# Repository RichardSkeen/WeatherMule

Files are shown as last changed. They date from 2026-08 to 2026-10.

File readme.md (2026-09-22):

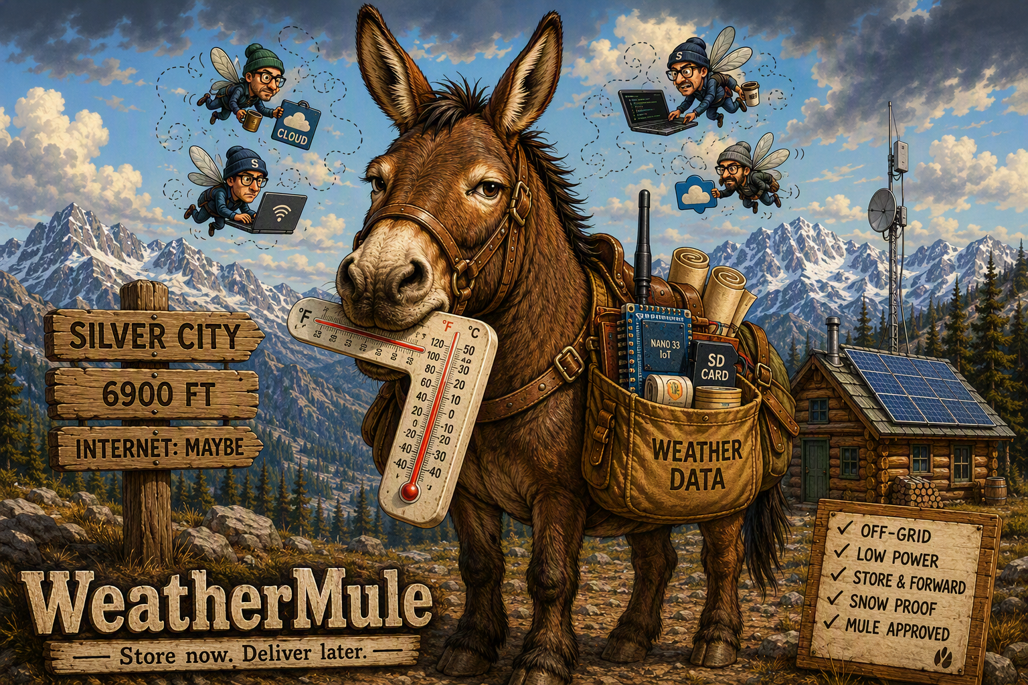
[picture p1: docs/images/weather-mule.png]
Weather Mule


*Not interested in deep dive?*
```cpp
if (!Interested)
{
    Read("docs/readme.md").JumpTo(start => "Technical Documentation" || "docs/technical/");
}
else
{
    enjoy = true;
}
```

# WeatherMule

> **Store now. Deliver later.**

WeatherMule is a store-and-forward weather relay built for remote weather stations where internet connectivity is less reliable than the weather itself.

Designed for an off-grid cabin in Silver City, California. WeatherMule captures weather observations, stores them locally on an SD card, and delivers them to PackStationWeather when network connectivity becomes available.

Because storms don't wait for Wi-Fi.

## Features

- 🐴 Store-and-forward weather delivery
- 💾 Local SD-card archive
- 🌲 Designed for remote and off-grid deployments
- 🔋 Low-power Arduino Nano 33 IoT platform
- 🌨️ Built for harsh mountain weather
- 📦 Automatic recovery of missing observations
- 🚫 No cloud dependency required

## Why?

Most weather systems assume the network is always available.

WeatherMule assumes the weather is always available.

The difference matters when the interesting weather arrives at the same time the internet disappears.

## Documentation

- docs/project-story.md
- docs/design.md
- docs/silver-city-use-case.md
- docs/deployment.md

## The Guiding Principle

> Save the weather first.  
> Figure everything else out later.

---

**WeatherMule:** Off-grid. Low-power. Store-and-forward. Snow-aware. Mule-approved.

### [Documentation Index](docs/readme.md)

---

## Related Project

### PackStationWeather

The destination at the end of the trail.

📖 [Building Our Own Pack Station](docs/project-story/pack-station-weather.md)

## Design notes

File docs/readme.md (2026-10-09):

# WeatherMule Documentation

This documentation is organized into technical references, project stories, hardware references, and supporting materials.

For readers new to the project, follow the documents below in order. Each document builds on the previous one and gradually moves from understanding what WeatherMule does to understanding how it is implemented.

## [Technical Documentation](technical/)

1. [quick-start.md](technical/quick-start.md)  
   Begin here. Provides a high-level introduction to WeatherMule and the quickest path to understanding the project.

2. [architecture.md](technical/architecture.md)  
   Describes the major components of WeatherMule and the responsibilities assigned to each subsystem.

3. [flow-storage.md](technical/flow-storage.md)  
   Describes the flow of data through the WeatherMule storage subsystem, from request to response.

4. [flow-application.md](technical/flow-application.md)  
   Describes the flow of data through the WeatherMule application, from weather station to storage and delivery.

5. [flow-weather-request.md](technical/flow-weather-request.md)  
   Describes the flow of a weather station request through the WeatherMule application, from request to response.

6. [flow-authentication.md](technical/flow-authentication.md)  
   Describes the flow of an authentication request through the WeatherMule application, from request to response.

7. [flow-upload-observation.md](technical/flow-upload-observation.md)  
   Describes the flow of an observation upload through the WeatherMule application, from request to response.

8. [flow-hole-processing.md](technical/flow-hole-processing.md)  
   Describes the flow of a hole processing request through the WeatherMule application, from request to response.

9. [source-map.md](technical/source-map.md)  
   Maps source files to responsibilities. Use this document when locating where specific functionality is implemented.

## [Project Story](project-story/)

The project stories describe how WeatherMule evolved, why design decisions were made, and lessons learned during development.

1. [silver-city-use-case.md](project-story/silver-city-use-case.md)  
   Describes the initial use case that motivated the WeatherMule project.

2. [life-of-a-weather-observation.md](project-story/life-of-a-weather-observation.md)  
   Explains how a weather observation moves through the system, from creation to storage and delivery.

3. [weather-station-data.md](project-story/weather-station-data.md)  
   Explains how the Ambient Weather protocol was discovered and validated.  

4. [pack-station-weather.md](project-story/pack-station-weather.md)  
   Describes how the PackStation weather station was integrated into WeatherMule.

5. [packbox-storage.md](project-story/packbox-storage.md)  
   Describes the design and implementation of the PackBox storage system.

6. [authentication.md](project-story/authentication.md)  
   Explains how authentication was implemented in WeatherMule.

7. [unload-weather.md](project-story/unload-weather.md)  
   Explains how the mule unloads weather observations to the pack station.

8. [holes.md](project-story/holes.md)  
   Explains how holes in the weather observation data are detected and processed.
## Future Development
#### V2
1.[v2-weather-station-manifest-design.md](future/v2/v2-weather-station-manifest-design.md)  
  Weather station manifest and configuration management.

## Hardware

Hardware-specific documentation is located in the hardware/ folder.

1. [ambient-weather-2000.md](hardware/ambient-weather-2000.md)  
2. [arduino.md](hardware/arduino.md)
3. [enclosure.md](hardware/enclosure.md)

## Reference Material

Reference documents contain vendor-specific information and supporting research used throughout the project.

1. [ambient-device-data-specs.md](reference/ambient-device-data-specs.md)  
   Reference documentation from Ambient Weather describing the weather station observation fields.

2. [protocol-discovery.md](reference/protocol-discovery.md)  
   Documents how the Ambient Weather protocol was analyzed, validated, and incorporated into WeatherMule.

---

## Related Project

### PackStationWeather

The destination at the end of the trail.

📖 [Building Our Own Pack Station](project-story/pack-station-weather.md)

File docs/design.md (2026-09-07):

# WeatherMule Design

## Overview

WeatherMule is a store-and-forward weather relay designed for locations where weather observations are more reliable than internet connectivity.

The primary objective is simple:

```text
Never lose weather observations.
```

WeatherMule receives weather data from an Ambient Weather WS2000, stores observations locally on SD card, maintains current weather statistics, and attempts to synchronize missing observations when connectivity allows.

---

# High-Level Architecture

```text
                 +----------------+
                 | Ambient Weather|
                 +--------+-------+
                          ^
                          |
                          |
                 +--------+-------+
                 |  WeatherMule   |
                 | Arduino Nano   |
                 +--------+-------+
                          ^
                          |
                          |
                 +--------+-------+
                 |     WS2000     |
                 +----------------+
```

The weather station transmits observations to both Ambient Weather and WeatherMule.

WeatherMule acts as a passive observer and backup delivery service.

---

# Core Design Principles

## Preserve Data First

Weather observations are more valuable than network status.

When in doubt:

```text
Save the observation.
```

Synchronization can happen later.

Lost observations cannot be recovered.

---

## Store Facts

WeatherMule stores the original weather observation exactly as received.

Example:

```text
GET /data/report/&PASSKEY=...
```

Derived values can always be recalculated later.

Original observations cannot.

---

## Simplicity Over Cleverness

WeatherMule is intended to operate:

- unattended
- off-grid
- on limited power
- in remote locations

Simple systems are easier to recover and maintain.

---

# Storage Model

WeatherMule uses two storage types.

## Packboxes (.box)

Packboxes contain the permanent weather archive.

Example:

```text
20260815.box
20260816.box
20260817.box
```

Each packbox contains observations received during a single day.

Example contents:

```text
GET /data/report/&PASSKEY=...
GET /data/report/&PASSKEY=...
GET /data/report/&PASSKEY=...
```

Packboxes are append-only.

Packboxes are the source of truth.

---

## Wrangler's Notebook (current.json)

current.json stores operational state.

Example:

```json
{
  "CurrentPackbox": "20260815.box",

  "LatestLocalUtc": "2026-08-15T22:18:21Z",
  "LatestAmbientUtc": "2026-08-15T17:58:21Z",

  "DailyLowTempF": 58.7,
  "DailyHighTempF": 90.9,

  "MaxWindGust": 15.88
}
```

This file contains:

- synchronization status
- current statistics
- upload progress
- current packbox information

Unlike packboxes, current.json may be overwritten frequently.

---

# WeatherRequest

WeatherMule receives weather observations using HTTP requests.

The WeatherRequest class:

```cpp
WeatherRequest
```

provides:

```text
Raw Request
+
Parsed Parameters
```

Example:

```text
GET /data/report/&PASSKEY=...
```

becomes:

```text
PASSKEY
dateutc
tempf
humidity
windspeedmph
...
```

The raw request is used for storage and replay.

The parsed values are used for statistics and reporting.

---

# Statistics

WeatherMule maintains a running summary of weather conditions.

Examples:

```text
Daily Low Temperature
Daily High Temperature

Maximum Wind Gust

Latest Observation

Rainfall Totals
```

Statistics are updated as observations are received.

Historical packboxes never need to be rescanned during normal operation.

---

# Synchronization Strategy

Traditional systems check:

```text
Is the network available?
```

WeatherMule attempts to answer:

```text
Is Ambient Weather missing observations?
```

Example:

```text
Ambient Latest:
17:58 UTC

WeatherMule Latest:
22:18 UTC
```

Result:

```text
Ambient is behind.
```

WeatherMule should determine which observations are missing and attempt synchronization.

The reason for the outage is irrelevant.

Possible causes include:

- Internet outage
- Ambient outage
- Router outage
- DNS failure
- Power interruption

WeatherMule cares only about whether the cargo was delivered.

---

# Timestamp Authority

WS2000 observations include:

```text
dateutc=YYYY-MM-DD HH:MM:SS
```

WeatherMule treats the weather station timestamp as authoritative for the observation.

This avoids dependence on local clocks and external time services.

---

# Future Work

Planned areas of investigation:

## Ambient Synchronization

Determine:

- Ambient upload destination
- Ambient response behavior
- Historical upload support
- Duplicate handling behavior

## Packbox Recovery

Determine optimal strategy for:

- locating missing observations
- replaying missed observations
- recovering after power loss

## Statistics

Expand locally maintained statistics while preserving simplicity.

---

# Design Vocabulary

WeatherMule uses a pack-train metaphor throughout the project.

| Term | Meaning |
|---|---|
| Cargo | Weather observations |
| Packbox | Daily `.box` file |
| Cargo Manifest | WeatherRequest |
| Wrangler's Notebook | current.json |
| Mule Train | Collection of packboxes |
| Delivery | Synchronization with Ambient |

Cute = Bad

Meaningful = Good

Cute + Meaningful = Priceless.

---

# Guiding Principle

The mule does not care why the cargo was not delivered.

The mule only cares whether the cargo was delivered.

## Possible WeatherMule Enclosure

The WeatherMule enclosure may be based on a modified 3D model of a pack mule. The mule body would be hollowed to contain the Nano 33 IoT, SD storage, wiring, and future expansion components. The saddle or tack assembly could serve as a removable service panel.

Potential source model:
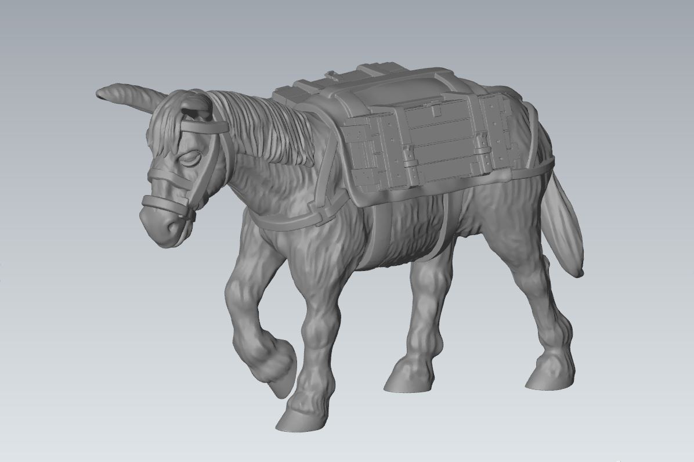
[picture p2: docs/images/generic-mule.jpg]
Mule 3D Model

[WeatherMule enclosure](https://www.myminifactory.com/object/3d-print-28-mm-generic-mule-tow-550193)

Ideas:
- Hollow body cavity for electronics.
- Saddle removable for maintenance access.
- OLED "Pack Tag" display mounted on a packbox.
- RGB status LED visible from outside the enclosure.
- USB access hidden beneath packbox or saddle.
- Device physically embodies the WeatherMule concept by carrying observations in digital packboxes to the PackStation.

Status: Future investigation. Verify model scale and available internal volume before purchase.

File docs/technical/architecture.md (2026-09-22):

# Purpose

WeatherMule is an embedded store-and-forward relay for weather observations.

Its responsibility is to:

- Receive weather observations from an Ambient Weather station.
- Preserve observations locally on removable storage.
- Forward observations to PackStationWeather.
- Recover from communication outages.
- Synchronize observations that were missed by the server.
- Operate unattended in environments where network connectivity may be unreliable.

WeatherMule treats the original weather observation as the source record and stores observations before attempting remote delivery. Local storage allows observations to be replayed later if PackStationWeather is unavailable.

The system is designed around reliability, recoverability, and low operational complexity rather than real-time delivery guarantees.

# Core Principles

## Preserve Data Before Delivery

Weather observations are stored locally before remote delivery is attempted. Local storage ensures observations remain available even when PackStationWeather, network connectivity, or supporting infrastructure are unavailable.

## Store Original Observations

WeatherMule preserves the original weather station observation as received. The original observation is considered the source record. Derived values and statistics may be recalculated later from the stored observations.

## Stored Original Observations Are the Source of Truth

Packboxes (.box files) serve as the authoritative record of observations retained by WeatherMule. Operational state and synchronization status may be recreated from packbox data if necessary.

## Recovery Is a Normal Operation

Network interruptions, power failures, and service outages are expected operating conditions. The system is designed to identify missing observations and recover delivery through synchronization processes.

## Prefer Simple and Observable Behavior

The system favors straightforward implementations that are easy to understand, troubleshoot, and recover in remote deployments. Simplicity is preferred over optimization unless a measurable benefit exists.

## Operate Unattended

WeatherMule is intended to operate for extended periods without human intervention. Normal processing, storage, delivery, and recovery operations should occur automatically whenever possible.

# System Components

## WeatherMule

WeatherMule is the application entry point.

Responsibilities:

- Connect to WiFi.
- Initialize local storage.
- Accept weather station requests.
- Coordinate upload and synchronization activities.
- Process holes when observations are not being received.

Primary file:

- WeatherMule.ino

## WeatherRequest

WeatherRequest parses incoming weather station requests and exposes observation values as key/value pairs.

Responsibilities:

- Parse incoming HTTP requests.
- Extract weather observation parameters.
- Provide access to individual values.
- Serialize observations for API transport.

Primary file:

- WeatherRequest.h

## Weather Station Interface

The Weather Station Interface receives observations from the weather station and coordinates local storage and delivery.

Responsibilities:

- Receive weather station requests.
- Validate observation requests.
- Store observations locally.
- Upload observations to PackStationWeather.
- Return HTTP responses to the weather station.

Primary file:

- WeatherStationRoutines.h

## Storage Subsystem

The Storage Subsystem manages persistent local storage using packboxes.

Responsibilities:

- Create daily packboxes.
- Append observations.
- Locate observations for synchronization.
- Read observations from historical packboxes.
- Maintain recovery data required for hole filling.

Primary file:

- StorageRoutines.h

## API Client

The API Client manages communication with PackStationWeather.

Responsibilities:

- Authenticate with PackStationWeather.
- Maintain session and refresh tokens.
- Upload observations.
- Report observations that cannot be recovered.
- Retrieve hole information.

Primary file:

- ApiClientRoutines.h

## Hole Processor

The Hole Processor recovers observations that are missing from PackStationWeather.

Responsibilities:

- Track holes returned by the server.
- Locate missing observations in packboxes.
- Upload recovered observations.
- Report observations that can no longer be located.
- Remove completed holes from processing.

Primary file:

- HoleRoutines.h

## API Response Parser

The API Response Parser provides lightweight JSON parsing for responses returned by PackStationWeather.

Responsibilities:

- Parse API responses.
- Extract property values.
- Convert JSON arrays and objects into navigable structures.

Primary file:

- ApiResponse.h

# Packboxes

Packboxes are the persistent storage mechanism used by WeatherMule.

A packbox is a daily append-only file containing the original weather station observations received during a single UTC date. Packboxes provide the durable record used for recovery, synchronization, and future processing.

## Naming

Packboxes are named using the observation date.

Examples:

2026-08-15.box
2026-08-16.box
2026-08-17.box

The date portion is derived from the observation timestamp rather than the device clock.

## Contents

Each line within a packbox contains a complete weather station observation in its original form.

Example:

GET /data/report/&PASSKEY=...

Observations are stored without modification to preserve the original source record.

## Append-Only Design

New observations are always appended to the end of the appropriate packbox.

Existing observations are never modified or removed.

This design:

- minimizes write operations
- simplifies recovery
- reduces the risk of corruption
- preserves original observations

## Source of Truth

Stored observations within packboxes are considered the authoritative record maintained by WeatherMule.

Synchronization, hole filling, and future processing operations are performed using observations recovered from packboxes.

Derived statistics and operational state may be recreated from packbox contents if necessary.

## Synchronization

When PackStationWeather identifies missing observations, WeatherMule locates the corresponding records within the appropriate packbox and replays them to the server.

Packboxes therefore serve as both:

- the local archive
- the recovery mechanism

## Recovery

Packboxes allow WeatherMule to recover from interruptions including:

- network outages
- server outages
- power interruptions
- device restarts

As long as observations have been successfully written to a packbox, they remain available for future delivery attempts.

# Authentication

WeatherMule authenticates with PackStationWeather using a two-stage token process.

## API Key

Each WeatherMule instance is configured with a unique API key.

The API key is a long-lived credential and is typically used only when establishing a new authenticated session.

## Check-In

WeatherMule performs a check-in operation when:

- no Session Token is available
- a Session Token has expired
- a Session Token has been revoked
- no Refresh Token is available
- a Refresh Token has expired
- a Refresh Token has been revoked

A successful check-in returns:

- Session Token
- Refresh Token

These tokens are stored in memory and used for subsequent communication.

## Token Lifecycle

The Session Token is intended for normal API operations and has a relatively short lifetime.

The Refresh Token has a longer lifetime and is used to obtain a replacement Session Token when the current Session Token expires.

During normal operation:

1. WeatherMule authenticates using the API Key.
2. PackStationWeather returns a Session Token and Refresh Token.
3. API requests use the Session Token.
4. When the Session Token expires, WeatherMule performs another check-in using the Refresh Token.
5. PackStationWeather returns a replacement Session Token.
6. Normal operation continues.

The API Key is normally not transmitted again until both token-based mechanisms become unavailable.

## Refresh Token Rotation

Refresh Tokens may be rotated during Session Token renewal.

When a new Refresh Token is issued, it inherits the remaining expiration period of the token it replaces rather than creating a new refresh window.

This approach:

- limits long-term exposure of a Refresh Token
- reduces repeated transmission of the API Key
- preserves the original refresh-token expiration policy
- allows token values to change periodically during normal operation

## Authentication Failure

If token-based authentication fails, WeatherMule falls back to API Key authentication by performing a new check-in.

Authentication failures do not affect local observation storage. Observations continue to be preserved within packboxes and may be replayed after authentication is restored.

# Holes

A hole represents a range of observations that PackStationWeather expects to exist but cannot locate within its observation history.

Holes are identified by PackStationWeather and returned to WeatherMule during normal upload operations.

## Hole Structure

A hole contains:

- Vendor Device Key
- From UTC
- To UTC
- Partially Filled (used only by WeatherMule to track progress)
- Byte Offset (used only by WeatherMule to track progress)

The time range defines the missing observations between FromUtc and ToUtc.

Example:

{
    "vendorDeviceKey": "...",
    "fromUtc": "2026-08-15T17:00:00Z",
    "toUtc": "2026-08-15T18:00:00Z",
    "partiallyFilled": false,
    "byteOffset": 0
}

Primary file:

Hole.h

## Hole Processing

When a hole is received, WeatherMule locates observations associated with the hole and gradually replays missing observations to PackStationWeather.

Hole recovery is performed incrementally rather than as a single batch operation. This allows WeatherMule to remain responsive to new observations while recovery is in progress.

Progress is tracked so recovery can resume efficiently between processing cycles.

Hole processing continues until the boundary identified by ToUtc is reached or until WeatherMule determines that additional observations are unavailable.

Holes are transient recovery instructions rather than permanent state.

Whenever a new observation is successfully uploaded, any unfinished holes are discarded. PackStationWeather returns a new set of holes if any still exist.

This allows PackStationWeather to remain the authority for determining which observations are still missing while keeping WeatherMule focused on recovering only currently relevant gaps.

# Recovery

WeatherMule is designed to recover from temporary interruptions without losing previously stored observations.

Recovery is based on the assumption that communication failures are normal operating conditions rather than exceptional events.

## Recovery Sources

Recovery is performed using observations stored in packboxes.

As long as an observation has been successfully written to a packbox, WeatherMule retains the information required to attempt future delivery.

## Recoverable Conditions

WeatherMule can recover from conditions including:

- network interruptions
- PackStationWeather outages
- authentication failures
- device restarts
- temporary power interruptions

Recovery occurs automatically during normal operation.

## Recovery Process

After communication with PackStationWeather is restored, WeatherMule uploads new observations as they are received.

PackStationWeather identifies any gaps in its observation history and returns the corresponding holes.

WeatherMule uses the holes to locate and replay missing observations from packboxes until the identified gaps have been resolved or until additional observations cannot be located.

## Recovery Authority

PackStationWeather is responsible for determining which observations are missing.

WeatherMule is responsible for locating and replaying observations requested by PackStationWeather.

This separation allows recovery decisions to be made using the server's complete observation history while allowing WeatherMule to focus on preservation and delivery of observations.

## Recovery Limitations

Recovery requires that observations have been successfully stored in a packbox.

Observations that were never received or could not be stored cannot be recovered.

When PackStationWeather requests observations that WeatherMule cannot locate, the condition is reported as Not Observed.

# Design Vocabulary

WeatherMule uses a pack-train metaphor to provide consistent terminology throughout the project.

| Term | Meaning |
|---|---|
| WeatherMule | The Arduino-based store-and-forward weather relay |
| Cargo | Weather observations |
| Packbox | A daily `.box` file containing stored observations |
| Mule Train | The complete collection of packboxes |
| [PackStationWeather](../pack-station-weather.md) | The server responsible for observation storage, authentication, and hole identification |
| Hole | A range of observations expected by PackStationWeather but not currently available in its observation history |
| Check-In | Authentication request used to obtain Session and Refresh tokens |
| Delivery | Successful upload of an observation to PackStationWeather |
| Replay | Resending a previously stored observation from a packbox |
| Not Observed | A condition indicating WeatherMule cannot locate an observation requested by a hole |

The design vocabulary exists to provide concise terminology for concepts that appear frequently throughout the codebase, documentation, and operational workflows.

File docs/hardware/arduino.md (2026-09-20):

# Arduino Nano Hardware

The PackStationWeather field stations use an Arduino Nano as the primary data acquisition controller. The Nano is responsible for collecting sensor measurements, managing local device interfaces, buffering readings as needed, and communicating with the WeatherMule data transport subsystem.

## Why the Nano?

The Arduino Nano provides several advantages for remote weather station deployments:

- Low power consumption
- Proven reliability in field environments
- Compact form factor
- Extensive sensor library support
- Simple USB programming and debugging
- Large community support and documentation

These characteristics make the Nano a practical choice for unattended deployments where stability and recoverability are more important than raw processing power.

## Architecture

The Nano serves as the weather station's edge controller.

Responsibilities include:

- Reading weather sensors
- Collecting environmental measurements
- Managing station health information
- Maintaining local operational state
- Providing data to WeatherMule for transport to PackStationWeather

```mermaid
flowchart TD
    A[Weather Sensors]
    B[Arduino Nano]
    C[Connection Carrier]
    D[WeatherMule Firmware]
    E[PackBox Storage]
    F[PackStationWeather API]

    A --> B
    B --> C
    C --> D

    D --> E
    D --> F
```

## Connection Carrier

The Arduino Nano is mounted on a Connection Carrier board.

There is no technical requirement to use this specific carrier. The primary reason it was selected is because there was one sitting in the parts drawer when the project started.

That said, it turned out to be a convenient choice because it provides screw-terminal connections, simplifies wiring, and makes field maintenance easier than loose jumper wires.

WeatherMule does not depend on any proprietary carrier-board functionality. The carrier simply provides convenient access to the Nano's I/O pins.

## Documentation

### Arduino Nano

Official hardware documentation:

https://docs.arduino.cc/hardware/nano-33-iot/

### Connection Carrier

Connection Carrier documentation:

https://docs.arduino.cc/hardware/nano-connector-carrier/

## Operating Environment

The Nano is designed to operate continuously in remote field locations. Weather station enclosures should provide protection from:

- Moisture
- Condensation
- Direct precipitation
- Dust
- Insects
- Excessive heat exposure

All external wiring should include proper strain relief and weather-resistant connectors appropriate for the deployment environment.

## Deployment Notes

The Nano firmware is developed specifically for the PackStationWeather ecosystem and may differ from reference Arduino examples.

When deploying or updating a station:

1. Verify firmware version.
2. Verify sensor connectivity.
3. Verify WeatherMule communication.
4. Verify accurate timestamps.
5. Confirm successful data delivery to PackStationWeather.

A successful deployment allows the station to collect weather observations locally while WeatherMule handles transport, synchronization, and recovery of missing observations.

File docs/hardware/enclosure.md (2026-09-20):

# WeatherMule Enclosure Concept

This document describes a proposed enclosure concept for WeatherMule.

The enclosure has not yet been printed, assembled, or field tested. At the time of writing, it exists only as a digital model and a growing list of ideas.

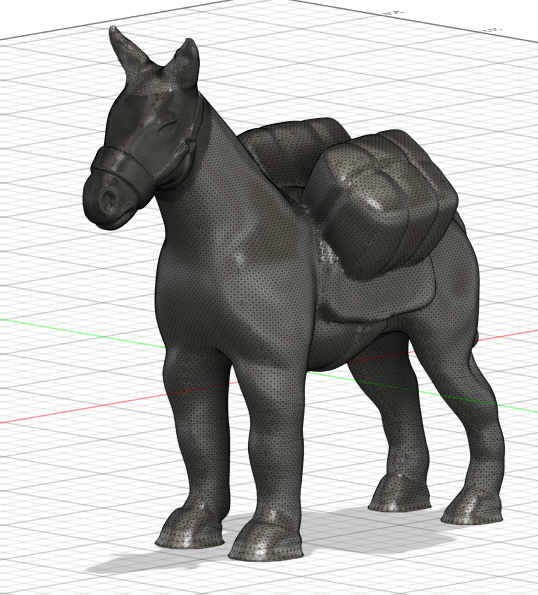
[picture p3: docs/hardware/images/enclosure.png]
Weatheer Mule Model


## Background

Most electronics projects eventually end up inside a generic plastic box.

While there is nothing wrong with that approach, the WeatherMule project presents a unique opportunity.

If the firmware responsible for collecting, storing, and delivering weather observations is called *WeatherMule*, perhaps the enclosure should look the part.

The current concept explores using a 3D printed pack mule as the enclosure for the Arduino Nano and Connection Carrier.

## Design Goals

The enclosure should:

- Protect the Arduino Nano and Connection Carrier
- Provide access to power and sensor connections
- Allow maintenance and firmware updates
- Be printable on a consumer-grade 3D printer
- Be easy to assemble and service
- Add a little personality to the project

The intent is not to create a sculpture. The intent is to create a practical enclosure that also happens to look like the project it contains.

## Why a Mule?

WeatherMule acts as a transporter of observations.

When a weather station reports data, the mule receives it, stores it when necessary, and delivers it to PackStationWeather when connectivity is available.

It is only fitting that the Arduino Nano should reside within the belly of a pack mule. After all, if the firmware is called WeatherMule, the hardware ought to look capable of carrying a few PackBoxes up a mountain trail.

## Proposed Layout

The current concept places the Arduino Nano and Connection Carrier within the body of the mule.

The saddlebags provide an interesting opportunity for future expansion and visual feedback.

Possible uses include:

- E-ink status displays
- Project branding
- Station identification
- Weather summaries
- Battery or power information
- Connectivity status

The final arrangement has not yet been determined and will likely evolve as prototypes are tested.

## Electronics

The current WeatherMule hardware is intentionally simple.

The design presently consists of:

- Arduino Nano
- Connection Carrier

WiFi connectivity is provided directly by the Nano, eliminating the need for additional networking hardware.

The enclosure should therefore remain relatively compact while still leaving room for future enhancements.

## Printing Considerations

Several design questions remain open:

- Should the mule be printed as a single assembly or multiple sections?
- How should access be provided to the electronics?
- Should the saddlebags be removable?
- How can wiring be routed cleanly?
- What level of weather resistance is practical?

These questions will be answered through prototype iterations as development progresses.

## Current Status

The enclosure remains a concept.

The CAD model represents an early design direction rather than a finished product.

As ideas go, however, it seems more appropriate than yet another anonymous project box.

Some projects hide their electronics in a plastic enclosure.

WeatherMule may eventually carry them in a saddlebag.

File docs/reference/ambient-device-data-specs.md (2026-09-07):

## Device Parameters

This lists all the parameters that a device might send. Note: Not all devices send all the parameters.

* winddir - instantaneous wind direction, 0-360º
* windspeedmph - instantaneous wind speed, mph
* windgustmph - max wind speed in the last 10 minutes, mph
* maxdailygust - Maximum wind speed in last day, mph
* windgustdir - Wind direction at which the wind gust occurred, 0-360º
* windspdmph_avg2m - Average wind speed, 2 minute average, mph
* winddir_avg2m - Average wind direction, 2 minute average, mph
* windspdmph_avg10m - Average wind speed, 10 minute average, mph
* winddir_avg10m - Average wind direction, 10 minute average, 0-360º
* humidity - Outdoor Humidity, 0-100%
* humidity1...humidity10 - humidity 1...10, 0-100%
* humidityin - Indoor Humidity, 0-100%
* tempf - Outdoor Temperature, ºF
* temp1f...temp10f - Temperature 1...10, ºF
* soiltemp1f...soiltemp10f - Temperature 1...10, ºF
* soilhum1...soilhum10 - Temperature 1...10, %
* leafwetness1...leafwetness8 - Leaf Wetness 1...8, Int, %
* soiltens1...soiltens4 - Soil Tension 1...4, Float, cb
* gdd - Growing Degree Days, Int, days
* etos - Evapotranspiration short, Float, in/day
* etrs - Evapotranspiration, tall, Float, in/day
* tempinf - Indoor Temperature, ºF
* leak1...leak4 - Leak Detection 1...4, 0=OK, 1=LEAK, 2=OFFLINEle
* battout - Outdoor Battery - OK/Low indication, Int, 1=OK, 0=Low (*Meteobridge Users* 1=Low, 0=OK) 
* battin - Indoor Battery - OK/Low indication, Int, 1=OK, 0=Low (*Meteobridge Users* 1=Low, 0=OK) 
* batt1...batt10 - OK/Low indication, Int, 1=OK, 0=Low (*Meteobridge Users* 1=Low, 0=OK) 
* batt_25 - PM2.5 Air Quality Sensor Battery indication, OK/Low indication, Int, 1=OK, 0=Low (*Meteobridge Users* 1=Low, 0=OK)
* batt_lightning - Lightning Detector Battery - 1=Low 0=OK
* batleak1...batleak4 - Leak Detector Battery - 1=Low 0=OK
* battsm1...battsm4 - Soil Moisture Battery - 1=OK, 0=Low
* batt_co2 - CO2 battery - 1=OK, 0=Low
* batt_cellgateway - Cellular Gateway - 1=OK, 0=Low
* hourlyrainin - Hourly Rain Rate, in/hr
* dailyrainin - Daily Rain, in
* 24hourrainin - 24 Hour Rain, in
* weeklyrainin - Weekly Rain, in
* monthlyrainin - Monthly Rain, in
* yearlyrainin - Yearly Rain, in
* eventrainin - Event Rain, in
* totalrainin - Total Rain, in (since last factory reset)
* baromrelin - Relative Pressure, inHg
* baromabsin - Absolute Pressure, inHg
* uv - Ultra-Violet Radiation Index, integer on all devices *EXCEPT* WS-8478.
* solarradiation - Solar Radiation, W/m^2
* co2 - CO2 Meter, ppm
* relay1...relay10 - Relay 1...10, 0 or 1
* pm25 - PM2.5 Air Quality, Float, µg/m^3
* pm25_24h - PM2.5 Air Quality 24 hour average, Float, µg/m^3
* pm25_in - PM2.5 Air Quality, Indoor, Float, µg/m^3
* pm25_in_24h - PM2.5 Air Quality 24 hour average, Indoor, Float, µg/m^3
* pm25_in_aqin - PM2.5 Air Quality Sensor indoor, AQIN sensor, Float, µg/m^3
* pm25_in_24h_aqin - PM2.5 Air Quality Sensor indoor, 24 hour running average, AQIN sensor, Float, µg/m^3
* pm10_in_aqin - PM10 Air Quality Sensor, Float, µg/m^3
* pm10_in_24h_aqin - PM10 Air Quality Sensor, 24 hour running average, Float, µg/m^3
* co2_in_aqin - Indoor CO2 from AQIN, Int, ppm
* co2_in_24h_aqin - Indoor CO2 from AQIN, 24 hour running average, Int, ppm
* pm_in_temp_aqin - Indoor PM sensor temperature, Float, ºF
* pm_in_humidity_aqin - Indoor PM sensor humidity, Int, %
* aqi_pm25_aqin - AQI derived from PM25, AQIN sensor, Int
* aqi_pm25_24h_aqin - AQI derived from PM25 Indoor, 24 hour running average, AQIN sensor, Int
* aqi_pm10_aqin - AQI derived from PM10 Indoor, AQIN sensor, Int
* aqi_pm10_24h_aqin - AQI derived from PM10 Indoor, 24 hour running average, AQIN sensor, Int
* aqi_pm25_in - AQI derived from PM25 IN, Int
* aqi_pm25_in_24h - AQI derived from PM25 IN, 24 hour running average, Int

* lightning_day - Lightning strikes per day, int
* lightning_hour - Lightning strikes per hour, int
* lightning_time - Last strike time, Datetime
* lightning_distance - Distance of last lightning strike, Float, miles
* tz - IANA Time Zone, String
* dateutc - Datetime, int (milliseconds from 01-01-1970, rounded down to nearest minute on server)
* Server calculated fields:
  * lastRain - Last time hourlyrainin > 0, date (calculated on server)
  * dewPoint - Dew Point, ºF (calculated on server)
  * feelsLike - if < 50ºF => Wind Chill, if > 68ºF => Heat Index  (calculated on server)
  * date - Human Readable Date, string  (converted on server from dateutc)
  * feelsLike1...feelsLike10 - feelsLike for sensors
  * dewPoint1...dewPoint10 - dewPoint for sensors
  * feelsLikein - Indoor Feels Like
  * dewPointin = Indoor dew Point

## Data Timing

The devices returned from the `/devices` endpoint contain a `lastData` parameter that contains the most up-to-date data we have for the device. Most devices update every minute, some update less frequently.  The timestamps are rounded to the nearest minute.

Queries for past data using the `/devices/:macAddress` endpoint are returned in 5 minute or 30 minute increments. There can be up to a 10 minute delay before the most recent data becomes available. If you need up-to-the-minute data please use the `/devices` endpoint or *forthcoming* realtime API. 

## Changelog
* 8.7.23 - remove aqi_pm25 & api_pm25_24h
* 2.22.23 - added many recent parameters
* 10.28.21 - add battery, lightning params
* 6.1.20 - weatherbridge users have a flipped battery bit
* 9.4.19 - pm25 Int -> Float. Added pm25_in, pm25_in_24h
* 8.21.19 - Added feelsLike1-10, dewPoint1-10, feelsLikein, dewPointin
* 5.20.19 - Added tz (Time Zone)
* 5.14.19 - Battery Fields changed from String to Integer

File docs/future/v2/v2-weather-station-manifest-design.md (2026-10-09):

# Weather Station Manifest Design

## Status

Future WeatherMule Version 2 design.

This document records a proposed manifest-driven design for supporting multiple weather stations. It is intentionally separated from the current implementation so work can remain focused on bringing PackStationWeather and the first WeatherMule deployment online.

## Purpose

WeatherMule should be able to receive, preserve, upload, and recover observations from multiple weather stations without embedding each station's field names or request format in the firmware.

The firmware should understand the stable manifest layout. PackStationWeather should own the current manifest contents.

## Current Limitation

The current WeatherRequest implementation contains weather-station-specific knowledge, including:

- The request recognition pattern.
- The device-key field name.
- The observation-date field name.
- Ambient-specific date normalization, including replacing `+` with `T`.

This works for the current Ambient station but requires firmware changes when another station uses different field names or request patterns.

## Design Principle

The manifest describes how WeatherRequest identifies and parses an observation. It does not contain vendor-specific processing instructions.

Every manifest property must have the same meaning for every supported weather station.

WeatherMule does not need to understand the observation's timezone or reinterpret the station's date format. It preserves the raw date value and the original request. PackStationWeather remains responsible for understanding what those values mean.

## Manifest File

The active manifest is stored on the WeatherMule SD card as:

```text
WeatherStationManifest.json
```

The file contains a JSON array with one entry for each weather station request format assigned to the mule.

Initial proposed layout:

```json
[
  {
    "RecognitionPattern": "data/report/",
    "DeviceKeyName": "PASSKEY",
    "DateFieldName": "dateutc"
  }
]
```

The property names may be refined during implementation, but their meanings should remain universal.

### RecognitionPattern

A string used to determine which manifest entry applies to an incoming raw request.

### DeviceKeyName

The name of the request field containing the weather station's device key.

### DateFieldName

The name of the request field containing the observation date exactly as supplied by the weather station.

## Request Processing

When WeatherMule receives a raw request:

1. It finds the manifest entry whose `RecognitionPattern` matches the request.
2. It creates a WeatherRequest using the raw request and the matching manifest entry.
3. WeatherRequest performs the remaining parsing and observation work.

Conceptually:

```cpp
WeatherStationManifest manifest = FindManifest(rawRequest);
WeatherRequest weatherRequest(rawRequest, manifest);
```

WeatherMule does not separately extract the device key, date, or key/value pairs.

## WeatherRequest Responsibilities

Given the raw request and the selected manifest, WeatherRequest is responsible for:

- Preserving the original raw request.
- Building the request's KeyValuePair collection.
- Extracting the device key using `DeviceKeyName`.
- Extracting and preserving `ObservationDateRaw` using `DateFieldName`.
- Producing the observation payload sent to PackStationWeather.
- Providing the information required to select the proper Packbox.
- Providing the information required for observation replay and hole processing.

The rest of WeatherMule continues to operate on WeatherRequest rather than depending directly on manifest field names.

## Observation Date

WeatherRequest adds an `ObservationDateRaw` property containing the date string exactly as received from the weather station.

WeatherMule does not:

- Replace `+` with `T`.
- Append `Z` or an offset.
- Determine the weather station's timezone.
- Convert the value to UTC.
- Convert the value to the PackStationWeather storage timezone.

PackStationWeather owns date interpretation and conversion because it has the weather-station configuration and timezone information.

## Packbox Processing

WeatherRequest supplies the information needed to place the observation into the correct Packbox.

Packboxes continue to preserve the original observation and remain the WeatherMule source of truth for recovery. The manifest changes how WeatherRequest discovers identifying values; it does not change the store-before-delivery principle.

The final Packbox naming rule for multiple stations will be determined during Version 2 implementation. The rule must prevent observations from different stations from being confused while preserving simple append-only storage and replay.

## Hole Processing

Hole processing continues to operate through WeatherRequest objects.

When an observation is read from a Packbox during recovery:

1. The stored raw request is matched to its manifest entry.
2. A WeatherRequest is created from the raw request and manifest.
3. WeatherRequest rebuilds its KeyValuePairs and identifying properties.
4. Existing hole-fill processing uploads the reconstructed observation.

WeatherMule does not need timezone knowledge to replay the original observation.

## Manifest Creation

A PackStationWeather user creates or assigns weather stations to a WeatherMule and uses the WeatherStationKeys function to generate the complete `WeatherStationManifest.json` file.

The initial manifest can be copied onto the WeatherMule SD card during provisioning.

The manifest is a complete replacement document, not a collection of incremental add, update, or delete instructions.

## Manifest Updates from PackStationWeather

PackStationWeather may return a manifest array during check-in.

Conceptual response:

```json
{
  "sessionToken": "...",
  "refreshToken": "...",
  "manifest": []
}
```

Update rule:

- An empty manifest array means the mule keeps its current local manifest.
- A non-empty manifest array is the complete current manifest and overwrites the local `WeatherStationManifest.json` file.

The mule does not compare entries, merge changes, add a station, remove a station, or determine what changed. PackStationWeather sends the complete manifest, and the mule replaces its local copy.

This supports changes such as:

- A field name changing from `dateutc` to `ObservationDateUtc`.
- A user assigning another weather station to the mule.
- A weather station being removed from the mule.
- A recognition pattern changing.

These are manifest-content changes and do not require firmware changes as long as the manifest layout remains compatible with the firmware.

## Firmware Compatibility Boundary

A firmware update is not required when only manifest values change.

Examples that should not require firmware changes:

- A different `RecognitionPattern`.
- A different `DeviceKeyName`.
- A different `DateFieldName`.
- Adding another station entry.
- Removing a station entry.
- Replacing the entire manifest.

A firmware update may be required when the manifest layout introduces a new concept that the existing WeatherRequest implementation does not understand.

The dividing line is:

> Changing manifest contents is configuration. Changing how manifest contents are used is firmware behavior.

## Responsibility Boundaries

### WeatherMule

- Loads the local manifest.
- Receives raw weather-station requests.
- Selects the matching manifest entry by `RecognitionPattern`.
- Passes the raw request and manifest to WeatherRequest.
- Stores the resulting observation.
- Uploads the resulting observation.
- Processes holes using reconstructed WeatherRequest objects.
- Replaces the local manifest when PackStationWeather supplies a non-empty complete manifest.

### WeatherRequest

- Interprets the raw request using the selected manifest.
- Builds KeyValuePairs.
- Preserves the original request.
- Extracts the device key.
- Preserves `ObservationDateRaw`.
- Provides the consistent observation interface used by storage, upload, and hole recovery.

### PackStationWeather

- Owns weather-station configuration.
- Generates the complete manifest assigned to a mule.
- Sends manifest replacements during check-in when appropriate.
- Interprets raw observation dates using the station's configuration.
- Performs timezone and storage-time conversions.
- Remains the authority for identifying holes.

## Expected Benefits

- One WeatherMule can carry observations for multiple weather stations.
- New stations can be assigned without merging configuration on the mule.
- Field-name and recognition-pattern changes can be deployed without reflashing firmware.
- WeatherRequest remains the single request-parsing boundary.
- WeatherMule remains independent of vendor-specific timezone and date quirks.
- PackStationWeather owns configuration and interpretation while WeatherMule owns preservation and delivery.
- The existing store-before-delivery and server-authoritative hole-recovery principles remain intact.

## Deferred Implementation Questions

The following details are intentionally deferred until Version 2 implementation:

- The C++ representation of a manifest entry.
- JSON parsing and memory limits for the manifest array.
- Maximum supported manifest entries.
- Behavior when no recognition pattern matches.
- Validation before replacing the current manifest.
- Safe file replacement if power fails during a manifest update.
- The final Packbox naming strategy for multiple weather stations.
- Whether the active manifest is cached in memory, read from SD on demand, or both.
- How PackStationWeather decides when to include a non-empty manifest in a check-in response.
- Compatibility behavior when a manifest requires a newer firmware layout.

## Summary

Version 2 makes WeatherMule manifest-driven without making it vendor-aware.

The mule receives a raw request, selects a manifest using `RecognitionPattern`, and gives both to WeatherRequest. WeatherRequest performs the parsing, preserves the device key and raw observation date, builds the observation, and supplies the information required for Packbox storage and hole recovery.

PackStationWeather owns and distributes the complete manifest. A non-empty manifest received during check-in replaces the mule's local manifest without comparison or merging.

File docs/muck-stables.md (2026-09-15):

# Muck Stables

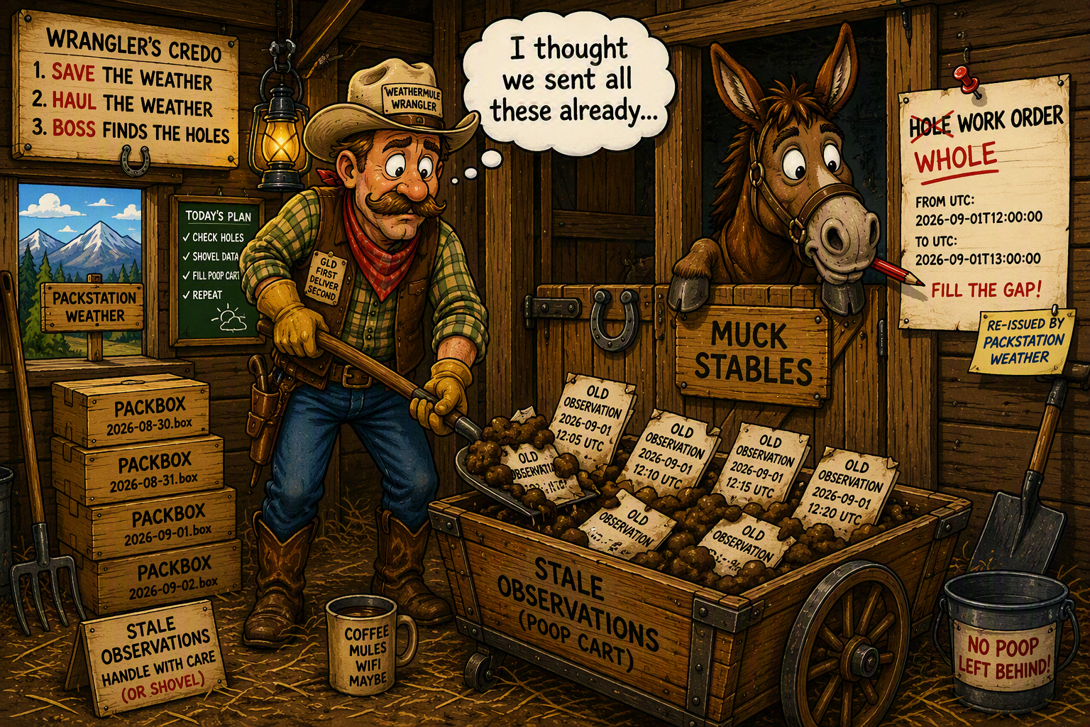
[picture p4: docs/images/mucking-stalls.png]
Mucking Stables


## Purpose

Muck Stables contains the WeatherMule hole-filling workflow.

The objective is simple:

- Keep hole processing lightweight.
- Avoid cadence calculations.
- Avoid date arithmetic.
- Avoid gap analysis on the mule.
- Let PackStationWeather determine what is missing.
- Let WeatherMule deliver whatever weather it possesses.

The mule should only need to:

1. Find the oldest hole.
2. Find the next observation after the hole bookmark.
3. Upload the observation.
4. Advance the bookmark.
5. Determine whether a hole contains observed weather or requires NotObserved.

---

# Hole Model

## Hole.h

Add:

```cpp
bool PartiallyFilled;
```

Meaning:

```text
false
    No observation has been uploaded
    between FromUtc and ToUtc.

true
    At least one observation has been
    uploaded between FromUtc and ToUtc.
```

This flag does not indicate that a hole has been completely filled.

The flag is only used to determine:

- I never had weather for this hole.
- I had at least some weather for this hole.

---

# Hole Processing

## ProcessHoles()

ProcessHoles() should:

1. Find the oldest hole.
2. Open the packbox containing FromUtc.
3. Locate the observation matching FromUtc.
4. Read the next observation.
5. Determine whether the next observation is ToUtc.
6. Upload observed weather or create NotObserved.
7. Update or remove the hole.

Pseudo-workflow:

```text
Oldest Hole
      ↓
Find FromUtc
      ↓
Read Next Observation
      ↓
Next Observation == ToUtc ?
```

If:

```text
PartiallyFilled == false
```

then:

```text
No observed weather exists
between FromUtc and ToUtc.
```

Send:

```text
NotObserved = 1
```

Remove hole.

If:

```text
PartiallyFilled == true
```

then:

```text
At least one observed weather record
was previously uploaded.
```

Remove hole.

PackStationWeather will recalculate any remaining holes during the next upload.

---

# StorageRoutines

## OpenPackBoxRead()

Responsibility:

```text
Open packbox containing FromUtc.
Locate row matching FromUtc.
Return the next observation row.
```

Hole processing should not need to know about files.

---

## ReadUntil()

Responsibility:

```text
Read until dateUtc matches FromUtc.
Return next observation row.
```

---

## TomorrowBoxFileName()

Responsibility:

```text
Given:

2026-09-12.box

Return:

2026-09-13.box
```

Used for end-of-packbox transitions.

---

# Packbox Boundary Handling

Example:

```text
2026-09-12.box

23:45
23:50
23:55 <- FromUtc
```

No additional rows exist.

ReadUntil() should:

```text
Open tomorrow's packbox
Read first row
Return first row
```

Example:

```text
2026-09-13.box

00:00
00:05
00:10
```

Return:

```text
00:00
```

Hole processing should not need to know whether the observation came from:

- current packbox
- tomorrow's packbox

StorageRoutines should handle that detail.

---

# Important Design Rule

WeatherMule does not know:

- reporting interval
- observation cadence
- expected observation count
- hole duration
- how many observations should exist

WeatherMule only knows:

```text
Find bookmark.
Read next observation.
Deliver cargo.
```

PackStationWeather remains the authority for:

- hole detection
- hole recalculation
- missing weather determination

The mule hauls cargo.

The station boss finds holes.

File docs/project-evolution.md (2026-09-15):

# WeatherMule Project Evolution

This document captures the evolution of WeatherMule, including discoveries, design changes, discarded ideas, lessons learned, and architectural decisions.

The goal is not to document what the software does.

The goal is to document why it became what it is.

---

# 2026-08-15

## Project Created

Created the WeatherMule GitHub repository.

Initial hardware target:

- Arduino Nano 33 IoT
- Arduino Nano Connector Carrier
- Ambient Weather WS2000
- SD Card storage

The original motivation is preserving weather observations from a remote cabin in Silver City, California, where internet connectivity is unreliable and winter access may be impossible for months.

---

## Rediscovered Previous Work

Located Arduino code from a much earlier attempt at receiving weather station data.

The old project contained:

- WeatherRequest.h
- KeyValuePair.h

The code was already capable of:

- Hosting a web server
- Receiving HTTP requests
- Parsing weather station parameters
- Displaying parsed weather values

This significantly reduced the amount of protocol reverse engineering required.

---

## First Successful Packet Capture

The WS2000 was configured to use the Ambient Weather Custom Server feature and send data directly to a Nano 33 IoT.

Captured packet:

```text
GET /data/report/&PASSKEY=... HTTP/1.1
```

with weather parameters including:

- PASSKEY
- stationtype
- dateutc
- tempf
- humidity
- windspeedmph
- windgustmph
- solar radiation
- UV
- rainfall
- indoor temperature
- indoor humidity
- pressure
- battery status

Major milestone achieved:

WeatherMule successfully received real weather observations from the weather station.

---

## Discovery: Custom Server Does Not Replace Ambient

Original assumption:

```text
WS2000
    |
    +--> WeatherMule
```

Observed behavior:

Ambient Weather continued receiving updates while the Custom Server was enabled.

Actual behavior:

```text
WS2000
    |
    +--> Ambient Weather
    |
    +--> WeatherMule
```

This greatly simplifies development because WeatherMule can be tested without disrupting the station's normal operation.

---

## Discovery: Stable PASSKEY

Observed that:

```text
PASSKEY=PHONYKEY5f3e...
```

remains constant between requests.

Initial suspicion:

- MAC address
- Cryptographic token
- Session identifier

Current suspicion:

- Device identifier
- Account identifier
- Station identifier

No evidence has been observed that the value changes from request to request.

---

## Discovery: No MAC Address Observed

Original investigation focused on identifying a MAC address in the weather packet.

A utility function named:

```cpp
MacToString()
```

was discovered in older code.

The function is never called.

Current theory:

A previous investigation into station identity may have begun but was never completed.

To date, no MAC address has been observed in captured weather packets.

---

## Discovery: dateutc Is The Important Timestamp

Captured packets contain:

```text
dateutc=YYYY-MM-DD HH:MM:SS
```

in UTC (Zulu) time.

This changes the architecture significantly.

Original thinking:

WeatherMule may need to maintain its own accurate clock.

Current thinking:

The weather station already provides the observation timestamp.

WeatherMule should preserve this timestamp exactly.

---

## Design Decision: Preserve Raw Requests

Initial thinking:

Store parsed weather values.

Revised decision:

Store the raw request exactly as received.

Reasoning:

Future protocol changes should not require changes to the storage format.

Store facts first.

Interpretation can always be derived later.

---

## Design Decision: Daily Packboxes

Traditional name considered:

```text
20260815.log
```

Chosen name:

```text
20260815.box
```

Reasoning:

WeatherMule stores weather cargo.

The Sierra Nevada pack mule metaphor became central to the project vocabulary.

A daily file is effectively a packbox containing weather cargo for that day.

Cute plus meaningful beats generic.

---

## Design Decision: Separate History From State

Current architecture direction:

### Packboxes

```text
20260815.box
20260816.box
...
```

Contain:

- Raw weather observations
- Append-only history
- Permanent storage

### current.json

Contains:

- Daily statistics
- Synchronization state
- Current packbox
- Latest known Ambient observation
- Upload bookkeeping

The packboxes are the source of truth.

current.json is merely the wrangler's notebook.

---

## Important Architectural Insight

WeatherMule should not determine whether to upload based on network availability.

Instead:

Determine whether Ambient Weather is behind.

If Ambient knows:

```text
17:58
```

and WeatherMule knows:

```text
22:18
```

then Ambient is missing data.

The reason why Ambient is missing data becomes irrelevant.

Possible causes:

- Internet outage
- Router outage
- DNS outage
- Ambient outage
- Power interruption

WeatherMule only cares whether cargo was delivered.

Not why it wasn't.

This idea may become the central synchronization strategy.

---

## 2026-08-16 - SD Card Access, exFAT, and the Missing Feed Bucket Incident

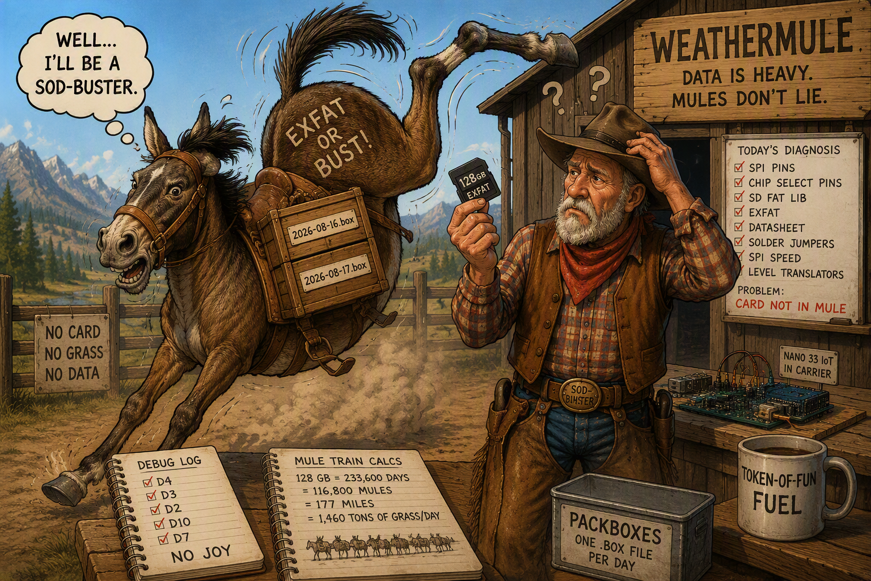
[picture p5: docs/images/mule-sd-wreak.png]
Mule Wreak


### Summary

WeatherMule storage moved from theory to working hardware today.

The Nano 33 IoT was tested on the Arduino Nano Connector Carrier using the onboard microSD card slot. The carrier datasheet confirms that the microSD card slot uses SPI communication and that D4 is the default SD card slave-select pin. Optional SD slave-select jumpers are available on D3 and D2. 

A 128 GB SDXC card formatted as exFAT was used for testing.

### Investigation

Initial testing with the standard Arduino SD library failed during card initialization.

To support exFAT media, SdFat v2.3.0 was installed and tested.

Multiple chip-select pins were tested:

```text
D4
D3
D2
D10
D7
```

SPI speed was reduced to 1 MHz.

All tests failed with:

```text
errorCode: 0x1
errorData: 0x0
```

The Nano 33 IoT reported the expected SPI pins:

```text
MISO = 12
MOSI = 11
SCK  = 13
SS   = 10
```

The Connector Carrier datasheet was reviewed to verify SD card SPI wiring and default chip-select assignments.

Several advanced theories were considered:

- Incorrect chip-select pin
- SPI timing issues
- Level translators on the carrier
- SDXC compatibility
- exFAT compatibility
- Solder jumper configuration
- Carrier board design issues

### Root Cause

While verifying that the card was formatted as exFAT, the SD card was removed from the Nano Connector Carrier and inserted into the desktop card reader.

After confirming the card was exFAT, the card was not reinserted into the Nano Connector Carrier before additional testing.

As a result:

```text
The grass was inspected.
The grass was Grade A exFAT.
The wrangler forgot to return the grass to the feed trough.
The mules did not eat.
```

### Resolution

The SD card was reinserted into the Nano Connector Carrier.

The SdFat QuickStart test was executed using chip-select pin D4 and immediately succeeded:

```text
Card successfully initialized.

Card size: 128000 MB
```

This confirmed:

```text
SPI communication works.
The Nano Connector Carrier SD slot works.
D4 is the correct default SD card chip-select pin.
The 128 GB SDXC card is supported.
SdFat can access the card successfully.
```

### Tokens-of-Fun Accounting

```text
Engineering Tokens Burned:
    Reasonable

Tokens-of-Fun Burned:
    Approximately 50,000

Hardware Replaced:
    None

Libraries Installed:
    SdFat v2.3.0

Actual Fix:
    Put the SD card back into the carrier.

Mules Harmed:
    0

Wrangler Embarrassment:
    Educational
```

### Design Decision

WeatherMule will use:

```text
SPI
SdFat v2.3.0
SdFs
FsFile
```

Storage strategy:

```text
One .box file per day.

Example:

2026-08-16.box
2026-08-17.box
2026-08-18.box
```

Raw weather station requests will be appended to the current day's packbox.

### Lessons Learned

Before investigating:

- SdFat
- SD libraries
- SPI timing
- Level translators
- Solder jumpers
- SDXC compatibility
- exFAT compatibility

Verify the SD card is physically present in the Carrier.

Official WeatherMule troubleshooting sequence:

```text
1. Verify mule exists.
2. Verify packbox exists.
3. Verify grass exists.
4. Verify grass is located near mule.
5. Only then investigate electronics.
```

### Current Status

```text
Nano 33 IoT                VERIFIED
Connector Carrier          VERIFIED
D4 SD_SS Pin               VERIFIED
128 GB SDXC Card           VERIFIED
SdFat Access               VERIFIED
Packbox Strategy           VERIFIED

Next Milestone:
Write and read the first .box file.
```

## 2026-08-16 - The Jug-Bust-Head Incident

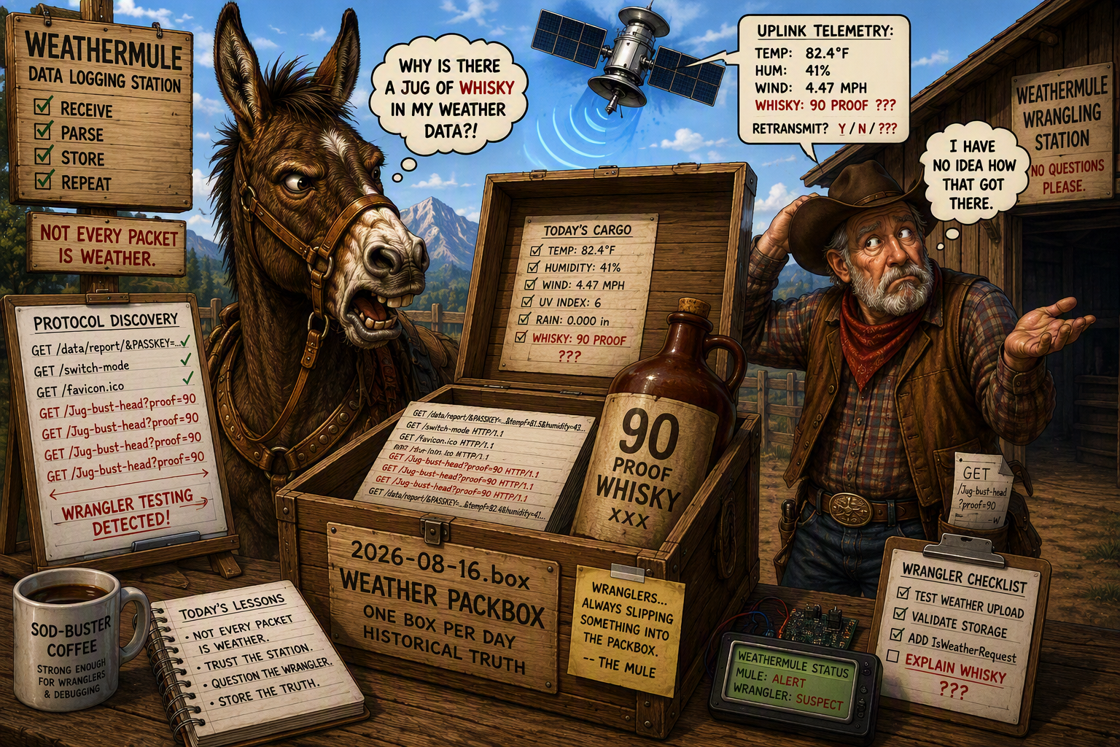
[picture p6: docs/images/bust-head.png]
Jug of Bust head


### Summary

The first successful WeatherMule packbox revealed an unexpected flaw in the original storage design.

The initial implementation faithfully stored every incoming HTTP request into the daily packbox.

The mule immediately demonstrated why this was a bad idea.

### Discovery

The first packbox contained legitimate weather observations:

```text
GET /data/report/&PASSKEY=...
```

Mixed in among the weather data were several unrelated requests:

```text
GET /switch-mode HTTP/1.1

GET /favicon.ico HTTP/1.1

GET /Jug-bust-head?proof=90 HTTP/1.1
```

The WeatherMule faithfully recorded all of them without complaint.

### Root Cause

The original assumption was:

```text
All requests arriving at WeatherMule are weather requests.
```

This assumption was disproven within minutes of testing.

While the weather station transmitted meteorological observations, the local wrangler began exploring alternate uses for the communications infrastructure.

The resulting packbox therefore contained both climate data and questionable cargo.

### Design Evolution

WeatherRequest now owns responsibility for determining whether an incoming request is weather related.

Example:

```cpp
bool IsWeatherRequest;
```

A request qualifies as weather traffic when:

```cpp
rawRequest.indexOf("/data/report/") >= 0
```

Packbox storage is now protected by:

```cpp
if(weatherRequest.IsWeatherRequest)
{
    AppendToBox(weatherRequest.rawRequest);
}
```

This prevents non-weather traffic from contaminating the historical archive.

### Important Observation

This incident validated a second architectural decision.

Weather parameters are intentionally stored as:

```cpp
Name
Value
```

pairs rather than a fixed structure.

Future sensors may transmit:

```text
leakdetector
soilmoisture
tanklevel
waterdepth
```

in any order.

WeatherMule records what arrives and does not assume a predefined parameter list.

### Packbox Integrity

A packbox represents a historical record of observations.

Packboxes should contain:

```text
Temperature
Humidity
Wind
Rain
Solar Radiation
Barometric Pressure
```

Packboxes should not contain:

```text
favicon.ico

switch-mode

Jug-bust-head?proof=90

90 proof whisky
```

### Official Incident Report

```text
Incident:
    Jug-Bust-Head

Classification:
    Wrangler Generated

Weather Data Lost:
    None

Weather Data Corrupted:
    None

Unexpected Cargo:
    favicon.ico
    switch-mode
    jug-bust-head

Root Cause:
    Wrangler testing activities

Mules Harmed:
    0

Whisky Consumed:
    Unknown

Tokens-of-Fun Burned:
    Approximately 15,000
```

### Lessons Learned

```text
Trust the weather station.

Question the wrangler.

Inspect all cargo before loading packboxes.
```

### Current Status

```text
SD Storage                VERIFIED
Packbox Creation          VERIFIED
Raw Request Logging       VERIFIED
Weather Request Detection IMPLEMENTED

Next Milestone:
Create current.json from weather-only requests.
```

### Historical Note

The illustration accompanying this incident depicts a WeatherMule discovering a jug of 90-proof whisky inside a weather-data packbox while a nearby communications satellite attempts to determine whether "proof" is a valid meteorological measurement.

The satellite remains unconvinced.

## 2026-8-17 - Control Endpoints and HTTP Response Cleanup

### Discovery

Early testing used a `/switch-mode` endpoint that toggled design logging on and off.

```text
192.168.1.222/switch-mode
```

While testing from a browser, logging could often be enabled successfully, but attempts to disable logging sometimes resulted in browser connection errors and the mode appearing to switch back on.

### Root Cause

The implementation toggled the state before generating the HTTP response.

Simplified example:

```cpp
inDesignMode = !inDesignMode;

if(inDesignMode)
{
    SendResponse();
}
```

When Design Mode was turned OFF, the response generation block was skipped. The browser received no HTTP headers and reported:

```text
ERR_EMPTY_RESPONSE
```

Because the request did not complete cleanly, the browser could retry or refresh, resulting in a second request that re-enabled Design Mode.

### Design Change

Toggle endpoints were replaced with explicit REST-style endpoints:

```text
/logging/on
/logging/off
```

Benefits:

- Idempotent operations
- Browser refreshes are safe
- Easier troubleshooting
- Future maintainers do not need to know the current state before issuing commands

Example:

```text
/logging/on
/logging/on
/logging/on
```

Always leaves logging enabled.

### HTTP Response Strategy

WeatherMule was updated to centralize HTTP response generation.

```cpp
Send200(...)
Send400(...)
Send404(...)
Send500(...)
Send503(...)
Send507(...)
```

A common response function now generates status headers:

```cpp
SendStatusResponse(...)
```

This ensures every request receives a valid HTTP response.

### Error Code Discussion

An early design question was whether WeatherMule should immediately map all storage and communication failures to specific HTTP status codes.

The project intentionally deferred that decision.

At this stage, WeatherMule can determine that a write operation succeeded or failed, but it cannot yet reliably distinguish between:

```text
SD card unavailable
Filesystem corruption
Card removed
SPI communication failure
Insufficient storage
Unexpected internal error
```

For that reason, returning:

```http
500 Internal Server Error
```

for unknown failures may be more appropriate than prematurely classifying failures as:

```http
503 Service Unavailable
```

or

```http
507 Insufficient Storage
```

Future versions may introduce a structured result such as:

```cpp
enum BoxWriteResult
{
    Success,
    SdUnavailable,
    OutOfStorage,
    OpenFailed
};
```

allowing more accurate HTTP status reporting.

### Logging Refactor

Direct `Serial.println()` calls began being replaced with:

```cpp
LogInformation(...)
```

Reasons:

- Centralized logging
- Easier future maintenance
- Ability to support multiple log destinations

Future logging destinations may include:

- Serial monitor
- SD card log files
- Remote telemetry service
- Combination of all three

This is particularly important because the Silver City deployment location does not allow convenient physical access during winter conditions.

### C++ Optimization Notes

Several functions were reviewed to reduce unnecessary object copying on Arduino hardware.

Example:

```cpp
void LogInformation(const String& logThis)
```

instead of:

```cpp
void LogInformation(String logThis)
```

Using `const String&`:

- Avoids copying the String
- Conserves RAM
- Prevents accidental modification
- Documents developer intent

The same pattern may be applied throughout the project for read-only String and WeatherRequest parameters.

### Operational Observation

During this work, weather graphs from the Silver City station showed extended overnight flat-line periods that were not present on the Three Rivers station.

This observation increased confidence that Ambient may not be backfilling weather observations during overnight internet outages.

If confirmed, this validates the primary WeatherMule objective:

```text
Store weather packets locally
    ↓
Survive internet outages
    ↓
Forward packets later
    ↓
Preserve complete weather history
```

### Lessons Learned

Never trust a toggle exposed through a browser.

A browser can click the same button twice much faster than a mule can explain what happened.

Also, always send a valid HTTP response.

A weather station may tolerate silence.

A web browser will file a complaint.

## 2026-08-17 - Daily Packbox Storage and Device Identification

### Daily Packbox Strategy

The original WeatherMule design considered maintaining a special "current" packbox file that would receive all incoming weather packets.

Further analysis showed that packet storage can be naturally partitioned using the weather station's `dateutc` value.

Example:

```text
dateutc=2026-08-15+22:18:21
```

The date portion is extracted:

```text
2026-08-15
```

and used to generate the packbox filename:

```text
2026-08-15.box
```

Benefits:

- No special "current box" logic required
- Packets automatically group by observation date
- Easier recovery after multi-day internet outages
- Simpler upload processing
- Reduced bookkeeping code

If connectivity is lost for several days:

```text
2026-08-14.box
2026-08-15.box
2026-08-16.box
2026-08-17.box
```

each day's observations accumulate in a separate packbox.

During recovery, WeatherMule can process packboxes chronologically, forwarding the oldest stored observations first and continuing until all backlog data has been transmitted.

This approach allows storage organization to be derived directly from the weather station timestamps rather than requiring WeatherMule to maintain additional tracking state.

### Offline Recovery Implications

Because every weather packet already includes a timestamp supplied by the weather station, WeatherMule can reconstruct historical transmission gaps after internet service is restored.

Example:

```text
Last successful cloud update:
2026-08-14 10:15:37

Current date:
2026-08-17
```

WeatherMule can determine which daily packboxes contain observations that have not yet been forwarded and process them in order.

This design may also support future reconciliation logic comparing locally stored observations with records already present in Ambient Weather services.

### Startup Device Identification

Startup diagnostics were enhanced to display additional network identification information.

Example startup output:

```text
Initializing SD card...
SD card initialized.
SSID: WiFi-IOT
IP: 192.168.1.1
Mac: 01:a6:b7:02:14:29
```

The MAC address was originally considered for use as a request header that could assist with device authentication.

Subsequent network discussions suggested that this may be unnecessary because networking equipment already identifies devices by MAC address at Layer 2.

Even if not used directly for authentication, including the MAC address in startup diagnostics provides several operational benefits:

- Network troubleshooting
- Verifying device identity
- DHCP reservation setup
- Router configuration
- Distinguishing multiple WeatherMule deployments

This became especially relevant after deployment planning for the dedicated IoT wireless network in Silver City.

Future deployment procedures may include assigning static DHCP reservations based on the WeatherMule MAC address so that router reboots do not require an onsite visit to determine a new IP address.

### Operational Principle

A mule carrying weather packets should always know:

```text
Who it is
Where it is
What day its cargo belongs to
```

The MAC address answers the first question.

The IP address answers the second.

Daily packboxes answer the third.

## 2026-08-18 - The Case of the Missing Packbox

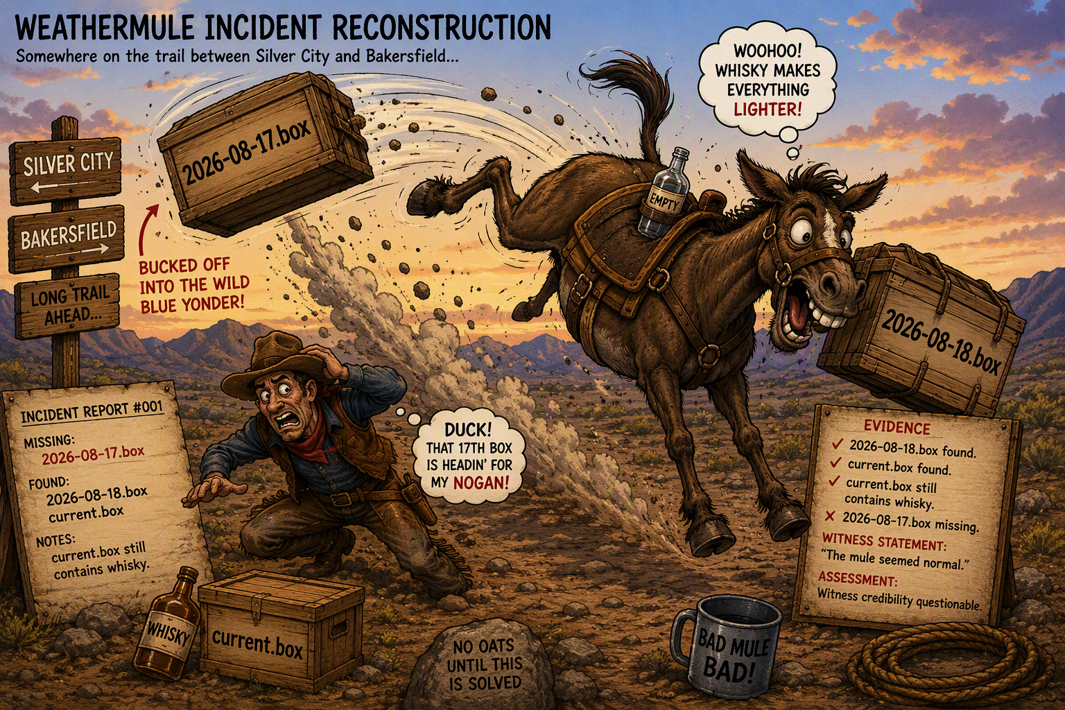
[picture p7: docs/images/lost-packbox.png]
Missing Packbox


During overnight testing of date-based packboxes, the WeatherMule
successfully created 2026-08-18.box but failed to retain
2026-08-17.box.

A subsequent investigation found:

- 2026-08-18.box present.
- current.box present.
- Whisky still present in current.box.
- 2026-08-17.box missing.

Initial blame was assigned to the mule.

However, a reconstruction of the event revealed the wrangler
attempting to avoid a flying 2026-08-17.box while the actual
whisky source remained adjacent to current.box.

Status: Investigation ongoing.

Current Theory:
The mule was framed.

## The Case of the Missing Packbox - Final Resolution

The WeatherMule was started between 8:00 PM and 9:00 PM PDT.

At that time, Ambient's `dateutc` value had already rolled
over to the next UTC day.

Since filenames are derived from `dateutc`, the first packbox
created was:

    2026-08-18.box

The expected:

    2026-08-17.box

was never actually created.

The subsequent forced rollover test successfully produced both:

    2026-08-18.box
    2026-08-19.box

confirming that packbox creation and retention were functioning
correctly.

Final Verdict:

    Mule: Not Guilty
    SD Card: Not Guilty
    Filename Logic: Not Guilty
    Wrangler: Confused by Zulu Time

--- 

## Documentation TODO

### Required Libraries

WeatherMule should maintain a list of required Arduino libraries so
new users can compile the project without hunting for dependencies.

Current libraries:

- WiFiNINA
- WiFiUdp
- SD (planned)
- ArduinoJson (planned for current.json, if used)

Future contributors should be able to install all required libraries
before opening WeatherMule.ino.

Consider adding a "Dependencies" section to quick-start.md.

---

## Project Motto

The weather does not stop because the internet is down.

Store the weather first.

Figure everything else out later.

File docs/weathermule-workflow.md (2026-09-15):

\# WeatherMule Workflow

\## What is WeatherMule?

WeatherMule sits between one or more weather stations and PackStationWeather.

Its job is simple:

1\. Receive weather observations.

2\. Save them immediately to local storage.

3\. Deliver them to PackStationWeather when possible.

4\. Help recover any historical observations that PackStationWeather is missing.

The mule's first responsibility is preserving weather data.

If the Internet disappears, the power fails, or PackStationWeather cannot be reached, the weather must still be safely stored on the SD card.

Weather can always be uploaded later.

Lost weather cannot be recreated.

\---

\# Core Philosophy

The mule follows a simple rule:

> Save first. Deliver second.

Every observation is written to storage before any network activity occurs.

The SD card is the mule's source of truth.

PackStationWeather is the synchronization authority.

The mule remembers weather.

PackStationWeather remembers what weather is missing.

\---

\# Startup Workflow

When the mule powers on:

1\. Connect to WiFi.

2\. Initialize SD card storage.

3\. Start the local HTTP server.

4\. Wait for incoming weather station requests.

No authentication occurs at startup.

Authentication is only performed when the mule needs to communicate with PackStationWeather.

\---

\# Live Observation Workflow

When a weather station submits an observation:

```text

Weather Station

&#x20;       |

&#x20;       V

Receive HTTP Request

&#x20;       |

&#x20;       V

Save Raw Request To Packbox

&#x20;       |

&#x20;       V

Upload Observation

&#x20;       |

&#x20;       V

Receive Hole List

&#x20;       |

&#x20;       V

Replace Existing Holes

```

\## Save First

The original weather station request is stored exactly as received.

Example:

```http

GET /data/report/\&PASSKEY=...\&tempf=72.5 HTTP/1.1

```

The mule does not modify or reconstruct observations before storage.

The original request remains permanently archived in a daily packbox file.

\---

\## Upload Latest Observation

After storage succeeds:

1\. Parse the observation into name/value pairs.

2\. Convert it into JSON.

3\. Deliver it to PackStationWeather.

Example:

```json

\[

&#x20; {

&#x20;   "FieldName": "tempf",

&#x20;   "FieldValue": "72.5"

&#x20; }

]

```

The mule does not need to understand sensors.

It simply hauls whatever cargo the weather station provides.

Unknown sensors are allowed.

Future sensors are allowed.

The mule carries sacks.

It does not inspect sacks.

\---

\# Authentication Workflow

WeatherMule uses three credentials:

\## API Key

Permanent credential configured in secrets.

Used only when:

\- First boot

\- Session recovery

\- Refresh failure

The API key survives reboot and power loss.

\---

\## Session Token

Obtained from PackStationWeather.

Used for normal authenticated operations.

Stored only in memory.

Never written to SD card.

\---

\## Refresh Token

Obtained from PackStationWeather.

Used to renew expired sessions.

Stored only in memory.

Never written to SD card.

\---

\# Check-In Workflow

If no session token exists:

```text

Use API Key

&#x20;       |

&#x20;       V

/api/checkin

&#x20;       |

&#x20;       V

Receive Session Token

Receive Refresh Token

```

Tokens remain in memory until:

\- Reboot

\- Power loss

\- Session replacement

\---

\# Session Recovery

If PackStationWeather returns:

```text

401 Unauthorized

```

The mule:

1\. Tries to check in using the refresh token.

2\. Receives replacement tokens.

3\. Retries the failed operation.

If refresh authentication fails:

1\. Discard tokens.

2\. Authenticate using the API key.

3\. Receive new tokens.

4\. Retry the operation.

\---

\# Hole Workflow

After a successful upload, PackStationWeather responds with a list of missing ranges.

These ranges are called holes.

Example:

```json

\[

&#x20; {

&#x20;   "vendorDeviceKey": "ABC123",

&#x20;   "fromUtc": "2026-09-01T00:00:00",

&#x20;   "toUtc": "2026-09-01T12:00:00"

&#x20; }

]

```

A hole means:

> PackStationWeather is missing weather between these two timestamps.

A hole does not contain weather.

A hole is simply a work order.

\---

\# Replacing Hole Lists

Whenever a live observation is uploaded:

```text

Discard Existing Holes

&#x20;       |

&#x20;       V

Store New Holes

```

The mule does not merge hole lists.

The mule does not attempt to calculate what is missing.

PackStationWeather is the authority.

If PackStationWeather says a hole exists, the hole exists.

If PackStationWeather no longer reports a hole, the mule forgets it.

\---

\# Historical Backfill Workflow

Historical synchronization only occurs when no live weather is waiting.

Fresh observations always have priority.

Expected workflow:

```text

No Live Weather

&#x20;       |

&#x20;       V

Select Oldest Hole

&#x20;       |

&#x20;       V

Find Matching Packbox

&#x20;       |

&#x20;       V

Locate Observation

&#x20;       |

&#x20;       V

Upload One Observation

&#x20;       |

&#x20;       V

Advance Hole

&#x20;       |

&#x20;       V

Return To Main Loop

```

Only one historical observation should be processed at a time.

This keeps the mule responsive to new weather arrivals.

\---

\# Hole Progress Tracking

The hole itself serves as the progress tracker.

Example:

Initial hole:

```text

FromUtc = 12:00

ToUtc   = 23:59

```

Observation delivered:

```text

12:05

```

Advance hole:

```text

FromUtc = 12:05:01

```

On the next pass, work resumes from the updated timestamp.

No separate cursor is required.

No file offsets are required.

No upload queue is required.

\---

\# New Weather Always Wins

If a new observation arrives while historical processing is underway:

```text

Stop Historical Work

&#x20;       |

&#x20;       V

Save New Observation

&#x20;       |

&#x20;       V

Upload New Observation

&#x20;       |

&#x20;       V

Receive New Holes

```

The mule is allowed to forget all previous hole state.

PackStationWeather already knows what is missing.

\---

\# Network Failure Handling

Network failures include:

\- WiFi outage

\- Router outage

\- DNS failure

\- Server unavailable

\- Timeout

\- TLS failure

When network operations fail:

```text

Keep Weather In Packboxes

&#x20;       |

&#x20;       V

Stop Delivery Attempts

&#x20;       |

&#x20;       V

Wait For Next Observation

```

Nothing is removed from storage.

Nothing is lost.

The mule simply waits for another opportunity to haul cargo.

\---

\# Storage Model

Weather is stored in daily packboxes.

Example:

```text

20260908.box

20260909.box

20260910.box

```

Characteristics:

\- Append only

\- Permanent archive

\- Local source of truth

\- Historical synchronization source

Every observation must be written before any delivery attempt occurs.

\---

\# Multiple Weather Stations

A mule may carry weather for multiple stations.

Stations are identified by:

```text

PASSKEY

```

which corresponds to:

```text

vendorDeviceKey

```

in hole responses.

A single packbox may contain observations from many stations.

Backfill processing uses the vendor device key to locate the correct observations.

\---

\# Recovery After Power Loss

After power loss the mule loses:

\- Session token

\- Refresh token

The mule retains:

\- API key

\- SD card

\- Packboxes

\- Historical weather

Upon restart:

1\. Reconnect to WiFi.

2\. Initialize storage.

3\. Wait for weather.

4\. Authenticate when needed using the API key.

5\. Continue normal operation.

No manual recovery steps should be required.

\---

\# Mental Model

The weather station creates weather.

WeatherMule preserves weather.

Packboxes protect weather.

PackStationWeather determines what is missing.

Holes are temporary work orders.

Fresh weather always comes first.

The mule may forget every hole at any moment.

PackStationWeather remembers.

The mule just hauls cargo.

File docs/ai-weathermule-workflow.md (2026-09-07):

## AI WeatherMule Workflow

### Purpose

This document defines the operational contract between WeatherMule and PackStationWeather.

An identical copy of this document should exist in both repositories:

- WeatherMule
- PackStationWeather

This document is intended primarily as AI context so future development, troubleshooting, documentation, and code generation remain consistent across both projects.

If implementation details conflict with this document, stop and resolve the conflict rather than silently inventing alternative behavior.

---

## Core Principle

Save the weather first. Figure everything else out later.

WeatherMule exists to preserve weather observations in environments where weather collection is more reliable than internet connectivity.

The first responsibility is always to save observations.

Delivery and synchronization are secondary concerns.

Lost weather cannot be recreated.

---

## AI Implementation Contract

The following rules are non-negotiable unless explicitly redesigned.

- MUST save every observation before attempting any network operation.
- MUST preserve the original weather station request exactly as received.
- MUST store observations in append-only daily `.box` files.
- MUST treat `.box` files as the local source of truth.
- MUST store session and refresh tokens only in memory.
- MUST NOT persist session tokens to SD card.
- MUST NOT persist refresh tokens to SD card.
- MUST authenticate using session tokens whenever possible.
- MUST renew expired sessions using refresh tokens.
- MUST fall back to API key authentication when necessary.
- MUST prioritize live weather over all historical synchronization activity.
- MUST immediately abandon historical processing when a new observation arrives.
- MUST discard all cached hole information when a new observation arrives.
- MUST ask PackStationWeather again what data is missing after processing a live observation.
- MUST treat missing ranges returned by PackStationWeather as authoritative.
- MUST NOT determine what observations are missing.
- MUST NOT maintain a persistent upload queue.
- MUST NOT maintain a persistent synchronization cursor.
- MUST NOT maintain a persistent file offset.
- MUST NOT maintain historical upload checkpoints.
- MUST distinguish network failures from HTTP responses.
- MUST stop delivery attempts after network failures.
- MUST wait for the next live observation before attempting delivery again.
- MUST remain recoverable after power loss.
- MUST not depend on continuous connectivity.

---

## System Roles

### Weather Station

Creates weather.

### WeatherMule

Preserves weather.

### Packboxes

Protect weather.

### PackStationWeather

Determines what weather is missing.

---

## Silver City Operating Environment

WeatherMule was designed specifically for environments like Silver City.

Typical operation:

```text
06:00 Network available
21:00 Network disabled
```

The network may be unavailable nightly to conserve power.

During winter:

- Solar charging may be limited.
- The network may operate only one or two hours per day.
- Storms may interrupt connectivity for days or weeks.
- A wrangler may need to ski or snowshoe in to restore service.

WeatherMule continues collecting weather regardless of connectivity.

The weather does not stop because the Internet is unavailable.

---

## Time Handling Rules

Humans think in local time.

WeatherMule uses UTC.

PackStationWeather uses UTC.

The weather station's `dateutc` field is authoritative.

The following MUST always use UTC:

- Observation timestamps
- Missing ranges
- Session timestamps
- Upload timestamps
- API timestamps

Summary:

```text
Humans think local.
WeatherMule thinks UTC.
PackStationWeather thinks UTC.
Weather station timestamps are authoritative.
```

---

## Storage Model

### Daily Packboxes

Examples:

```text
20260829.box
20260830.box
20260831.box
```

Characteristics:

- Append-only
- Stored on SD card
- Permanent archive
- Local source of truth
- Historical synchronization source

Every observation MUST be written to the appropriate packbox before any network activity.

### Raw Observation Storage

WeatherMule stores the original request exactly as received.

Example:

```text
GET /data/report/&PASSKEY=...&dateutc=2026-08-31+13:05:00&tempf=72.5 HTTP/1.1
```

WeatherMule never reconstructs weather observations.

Lost observations cannot be recreated.

---

## Parsed Observation Format

Raw observations are converted into name/value pairs before API delivery.

Example:

```json
[
  {
    "FieldName": "tempf",
    "FieldValue": "72.5"
  },
  {
    "FieldName": "humidity",
    "FieldValue": "58"
  }
]
```

The raw request remains stored regardless of delivery success.

---

## Authentication Model

### Permanent API Key

Every mule has a permanent API key.

The API key:

- Survives reboot
- Survives power loss
- Survives token expiration
- Identifies the mule

The API key is the root credential.

### Session Token

Session tokens:

- Stored in memory only
- Used for authenticated API requests
- Never persisted

### Refresh Token

Refresh tokens:

- Stored in memory only
- Used only with `api/checkin`
- Never persisted

### Initial Check-In

When no session token exists:

```text
Authorization: Bearer <ApiKey>
```

Request:

```text
POST api/checkin
```

Response:

```json
{
  "sessionToken": "...",
  "refreshToken": "..."
}
```

Store both tokens in memory.

### Session Renewal

If PackStationWeather returns:

```text
401 Unauthorized
```

Then:

```text
Authorization: Bearer <RefreshToken>
POST api/checkin
```

Receive replacement tokens.

Retry the interrupted operation.

### Refresh Failure

If refresh token renewal fails:

```text
Discard tokens.
Authenticate with API key.
Receive new tokens.
Retry operation.
```

### Power Loss

Power loss destroys:

```text
SessionToken
RefreshToken
```

Power loss does NOT destroy:

```text
ApiKey
Packboxes
```

Upon restart:

```text
Authenticate with ApiKey.
Get new tokens.
Continue.
```

---

## Main Loop Philosophy

WeatherMule is effectively single threaded.

Pseudo-code:

```text
Loop forever

    If weather is waiting
        ProcessIncomingWeather()
        Continue

    ProcessOneBackfillObservation()
```

Fresh weather always has priority.

Historical synchronization only occurs when no live observation is waiting.

---

## Live Observation Workflow

```text
Receive weather request
        |
        V
Save raw observation to packbox
        |
        V
Ensure authenticated
        |
        V
Convert observation to JSON
        |
        V
POST api/unload
        |
        V
Receive hole list
        |
        V
Replace current hole list
```

When a new observation arrives:

```text
Forget the entire Hole-Kit-and-Caboodle.
```

The previous hole list is discarded.

PackStationWeather will provide a fresh authoritative hole list.

---

## Hole Definition

A hole is a missing range of observations for a specific weather station.

Example:

```json
[
  {
    "vendorDeviceKey": "B8BF967E5C9153DF3A2FA5ECC3A5841B",
    "fromUtc": "2026-08-28T12:00:15",
    "toUtc": "2026-08-28T23:59:15"
  }
]
```

Properties:

```text
vendorDeviceKey
    Weather station identifier.
    Equivalent to PASSKEY.

fromUtc
    Beginning of missing range.

toUtc
    End of missing range.
```

A hole is NOT a list of observations.

A hole represents a missing time range.

Multiple holes may exist:

- Different missing ranges for one station.
- Different missing ranges for multiple stations.

---

## Historical Backfill Workflow

WeatherMule stores only holes.

WeatherMule does NOT queue observations.

The packboxes already contain the observations.

Pseudo-code:

```text
Find oldest hole by FromUtc

Determine packbox containing FromUtc

Read forward from top of file

Find first observation where:

PASSKEY == VendorDeviceKey

and

dateutc >= FromUtc

and

dateutc <= ToUtc

Send observation

Advance hole FromUtc forward

Return immediately
```

Only one historical observation is processed per call.

---

## Hole Progress Tracking

The hole itself acts as the progress tracker.

Example:

Initial hole:

```text
FromUtc = 12:00
ToUtc   = 23:59
```

Observation found:

```text
12:05
```

Upload observation.

Advance:

```text
FromUtc = 12:05:01
```

Next pass:

```text
Find next observation after 12:05
```

No separate cursor is required.

No file position is required.

No upload checkpoint is required.

---

## Multiple Weather Stations

A mule may carry weather for multiple stations.

All observations may exist in the same packbox.

Example:

```text
08:00 Station A
08:05 Station B
08:10 Station A
08:15 Station B
```

Stations are distinguished by:

```text
PASSKEY
```

which corresponds to:

```text
vendorDeviceKey
```

in hole responses.

When multiple holes exist:

```text
Process the hole with the oldest FromUtc.
```

As individual holes advance, WeatherMule naturally shifts work between stations.

No special scheduling logic is required.

---

## Hole Completion

When:

```text
FromUtc >= ToUtc
```

the hole is complete.

Remove the hole.

Continue with the next oldest hole.

When no holes remain:

```text
Wait for the next live observation.
```

---

## New Weather Interrupts Everything

If a new observation arrives while processing holes:

```text
Stop historical work.
Discard all hole state.
Save observation.
Send observation.
Receive fresh holes.
Continue.
```

WeatherMule never attempts to remember where it stopped.

PackStationWeather already knows.

---

## Network Failure Handling

Examples:

- DNS failure
- WiFi outage
- Router outage
- Internet outage
- TLS failure
- Timeout

Response:

```text
Keep weather in packboxes.
Stop delivery attempts.
Wait for next observation.
Try again later.
```

No special queue is required.

---

## Synchronization Authority

PackStationWeather owns synchronization knowledge.

WeatherMule owns weather cargo.

Conversation:

```text
WeatherMule:
    Here is the latest observation.

PackStationWeather:
    Thank you.
    Here is what I am missing.

WeatherMule:
    I will haul what I can while the trail is open.
```

WeatherMule never cares why data is missing.

WeatherMule only cares what PackStationWeather needs.

---

## State Recovery

WeatherMule must be recoverable using only:

- API Key
- SD card
- Packboxes
- New observations
- Hole ranges returned by PackStationWeather

Recovery must NOT require:

- Stored session tokens
- Stored refresh tokens
- Upload queues
- Synchronization checkpoints
- File offsets
- Backfill cursors

---

## Final Mental Model

```text
The weather station creates weather.

WeatherMule preserves weather.

Packboxes protect weather.

PackStationWeather determines what is missing.

Holes are temporary work orders.

The hole itself tracks progress.

Fresh weather always comes first.

The mule may forget the entire Hole-Kit-and-Caboodle at any moment.

PackStationWeather remembers.
The mule hauls cargo.

The network may disappear.

The mule does not panic.

The weather remains safe.
```

## Final Rule

```text
The mule does not care why the cargo was not delivered.

The mule only cares whether the cargo was delivered.
```

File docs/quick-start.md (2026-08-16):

# Quick Start

This guide assumes:

- Arduino Nano 33 IoT
- Nano Connector Carrier
- Ambient Weather WS2000

Estimated setup time: About as long as it takes to saddle a mule.

---

## Step 1 - Clone The Repository

```bash
git clone <repository-url>
```

---

## Step 2 - Configure Secrets

Copy:

```text
weathermule-secrets.example.h
```

to:

```text
weathermule-secrets.h
```

and provide your own values.

```cpp
#define SECRET_SSID "<SSID here>"
#define SECRET_PASS "<WiFi password here>"

#define AMBIENT_API_KEY "<API Key here>"
#define AMBIENT_APP_KEY "<App Key here>"
```

The mule is too stubborn to travel unless you whisper sweet credentials in its ear.

---

## Step 3 - Open The Project

Open:

```text
WeatherMule.ino
```

using the Arduino IDE.

Select:

```text
Board:
    Arduino Nano 33 IoT
```

and the appropriate COM port.

---

## Step 4 - Upload

Compile and upload the sketch.

Open the Serial Monitor.

Expected output:

```text
Connecting to WiFi...
SSID: YourWiFi
192.168.x.x
```

---

## Step 5 - Configure The Weather Station

On the WS2000:

```text
Weather Services
    Custom Server
```

Configure:

```text
Server IP:
    <WeatherMule IP>

Port:
    80
```

Recommended development cadence:

```text
1 Minute
```

Recommended production cadence:

```text
5 Minutes
```

---

## Step 6 - Verify Packet Reception

When a weather update arrives you should see output similar to:

```text
PASSKEY: 4b7d92e1c8runningtothebarnPHONYKEY5f3e8a1c

tempf: 90.9

humidity: 27

windspeedmph: 4.25
```

If you see weather values, the mule is receiving cargo.

---

## Current Status

Current prototype functionality:

✅ Receive WS2000 weather packets

✅ Parse weather parameters

✅ Preserve raw HTTP requests

🔄 SD card packboxes (.box)

🔄 current.json state tracking

🔄 Ambient synchronization

🔄 Store-and-forward delivery

---

## Next Steps

If this is your first visit to WeatherMule:

- Read [Silver City Use Case](silver-city-use-case.md)
- Read protocol-discovery.md
- Read [Design](design.md)

These documents explain why the mule exists and where the trail currently leads.

---

Remember:

**Save the weather first. Figure everything else out later.**

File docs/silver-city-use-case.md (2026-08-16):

# Silver City Use Case

## Why WeatherMule Exists

WeatherMule was not created as a general-purpose weather platform.

It was created to solve a specific problem in a specific place.

That place is Silver City, California.

The weather station that inspired WeatherMule can be viewed here:

[Silver City Weather Station](https://ambientweather.net/dashboard/7e3f5598bc3b9789186fff20dac521d)

Elevation: 6,900 feet.

Internet availability: Maybe.

Snow availability: Definitely.

## The Environment

The primary deployment target is an off-grid cabin operating from solar power and battery storage.

Internet connectivity is provided through a shared community Wi-Fi network. The network may become unavailable due to:

- Power limitations
- Equipment failures
- Weather conditions
- Seasonal access limitations
- Upstream internet outages

Unlike most connected devices, a weather station continues collecting observations whether the internet is available or not.

The weather does not stop because the internet is down.

## The Problem

Traditional cloud-connected weather stations assume that observations can be uploaded immediately.

When connectivity is lost, observations may never reach their destination.

This is particularly problematic because some of the most interesting weather events often occur during storms, power interruptions, and poor network conditions.

Examples include:

- Overnight low temperatures
- Winter storms
- High wind events
- Extended snowfall periods

These are often the exact observations that users want to preserve.

## WeatherMule's Job

WeatherMule acts like a Sierra Nevada pack mule.

When the road is open:

```text
Weather Station
        |
        v
Ambient Weather
```

When the road is closed:

```text
Weather Station
        |
        v
WeatherMule
        |
   Packboxes (.box)
```

When the road opens again:

```text
Packboxes (.box)
        |
        v
Ambient Weather
```

WeatherMule does not create weather.

WeatherMule does not modify weather.

WeatherMule carries weather observations until they can be delivered.

## Design Decisions Driven By This Use Case

### Arduino Hardware

The target environment values reliability, simplicity, low power consumption, and long unattended operation.

An Arduino Nano 33 IoT consumes far less power than traditional computers and can remain operational for long periods on limited power budgets.

### SD Card Storage

Observations must survive:

- Internet outages
- Ambient Weather outages
- Router restarts
- Power interruptions

WeatherMule stores observations locally before attempting delivery.

### Daily Packboxes

Observations are stored in daily packboxes using the `.box` file extension.

Examples:

```text
20260815.box
20260816.box
20260817.box
```

Each packbox contains the weather cargo collected during a single day.

### The Wrangler's Notebook

WeatherMule maintains a small state file called:

```text
current.json
```

The file contains:

- Current packbox
- Daily statistics
- Synchronization state
- Delivery status

This allows WeatherMule to recover quickly after power loss without scanning every packbox.

## Success Criteria

A successful WeatherMule deployment should be able to:

- Continue collecting observations during extended internet outages.
- Survive power interruptions without data loss.
- Operate unattended for months.
- Preserve significant weather events.
- Synchronize missing observations when connectivity returns.
- Remain simple enough to troubleshoot years later.

## Guiding Principle

When faced with a design decision:

**Save the weather first. Figure everything else out later.**

Because weather observations can be stored and delivered later.

Lost observations are gone forever.

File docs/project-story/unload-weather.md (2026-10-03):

## Unloading Cargo

By the time an observation reaches this stage of the journey, the most important work is already complete.

The weather has been preserved in a packbox.

The observation is safe.

Now the mule attempts delivery.

### An Impassable Trail

Sometimes the mule never reaches the pack station.

A storm may close the trail. A bridge may wash out. Heavy snow may make the pass impassable. The pack station may sit beyond a canyon where no message can get through.

In those situations, there is no paperwork to examine and no gatekeeper to argue with. The mule never arrives at the station.

The cargo remains safely packed in the mule train's packboxes. Nothing is discarded. Nothing is forgotten.

The mule simply waits.

Eventually the weather changes, the trail opens, and the journey can continue. When that day comes, the cargo is still there exactly as it was when the trail disappeared.

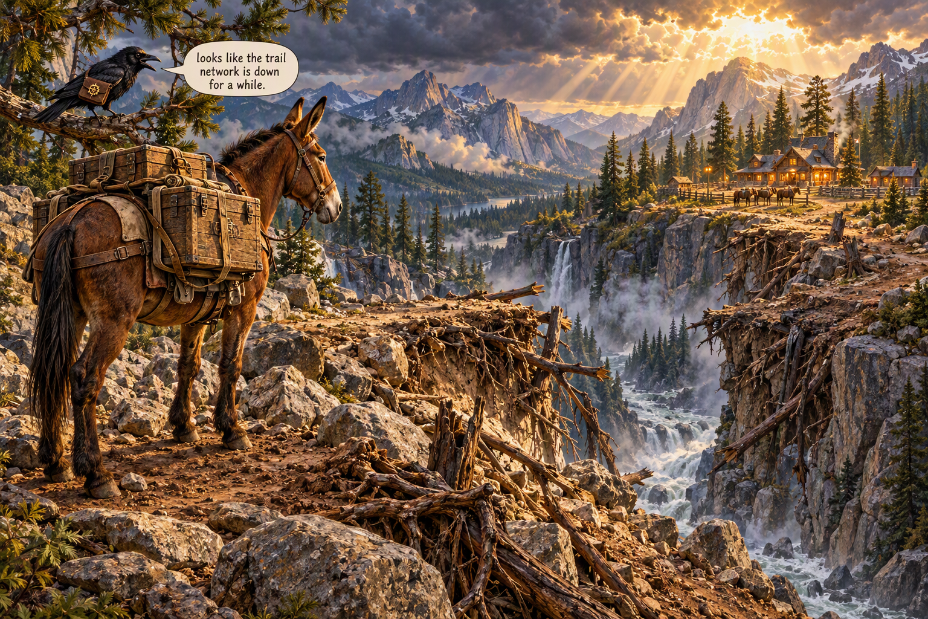
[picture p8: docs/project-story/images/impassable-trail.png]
Impassable Trail


### The Hitching Rail

*Implementation: [ApiClientRoutines.h](../../ApiClientRoutines.h) [ApiResponse.h](../../ApiResponse.h)* 

Weather observations are delivered through:

```http
POST /api/unload
```

When the mule arrives carrying weather cargo, it first attempts to use its existing session token.

If the session remains valid, the mule unloads immediately.

```mermaid
flowchart TD

    A[Observation Saved To Packbox]
      --> B[Arrive At Hitching Rail]

    B --> C[Attempt Unload]

    C -->|Session Valid| D[Upload Observation]

    C -->|401 Unauthorized| E[Visit Check-In Station]

    E --> F[Receive New Tokens]

    F --> D
```

The check-in station only becomes part of the trip when the mule's travel papers have expired.

Most deliveries never require a check in.

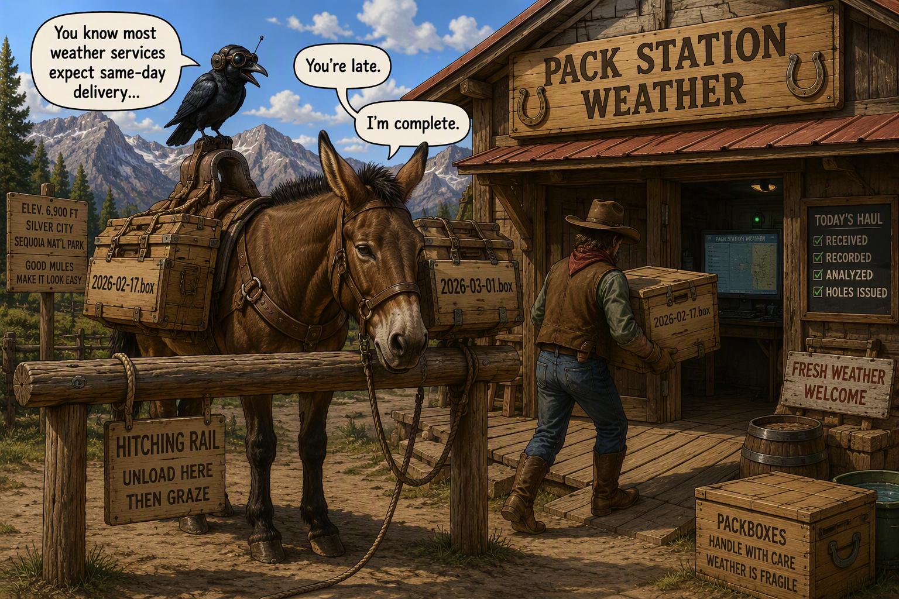
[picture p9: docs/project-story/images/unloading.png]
Unloading Weather


### Unloading Weather

WeatherMule converts the incoming observation into a collection of field/value pairs and submits them to PackStationWeather.  
*Implementation: [WeatherRequest.h](../../WeatherRequest.h)*

The server records the observation and evaluates whether any weather appears to be missing.

If missing observations are detected, the response contains a list of holes.

Conceptually:

```mermaid
flowchart TD

    A[Upload Observation]
      --> B[PackStationWeather Records Observation]

    B --> C[Analyze Observation History]

    C --> D[Return Hole List]
```

One delivery accomplishes two jobs.

The current weather is delivered.

The next recovery tasks are assigned.

### One Source Of Truth

A key design decision was that PackStationWeather owns synchronization state.

WeatherMule does not attempt to determine what observations are missing.

WeatherMule does not attempt to calculate holes.

WeatherMule simply follows the instructions returned by the pack station.

The mule carries cargo.

The pack station keeps the books.

### The Next Job

The hole list returned from an unload operation becomes the mule's next set of work orders.

Those work orders are called holes.

The next chapter explains how the mule searches its packboxes for missing cargo and gradually fills those holes one observation at a time.

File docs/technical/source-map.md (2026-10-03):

# Source Map

## Design Ownership

WeatherMule is organized around a small number of focused subsystems. Each major source file owns a specific part of the application's behavior.

- Application flow is implemented by `WeatherMule.ino`.
- Weather request handling is implemented by `WeatherStationRoutines.h`.
- Observation parsing and representation are implemented by `WeatherRequest.h`.
- Storage and replay are implemented by `StorageRoutines.h`.
- Authentication and API communication are implemented by `ApiClientRoutines.h`.
- Hole recovery is implemented by `HoleRoutines.h`.
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

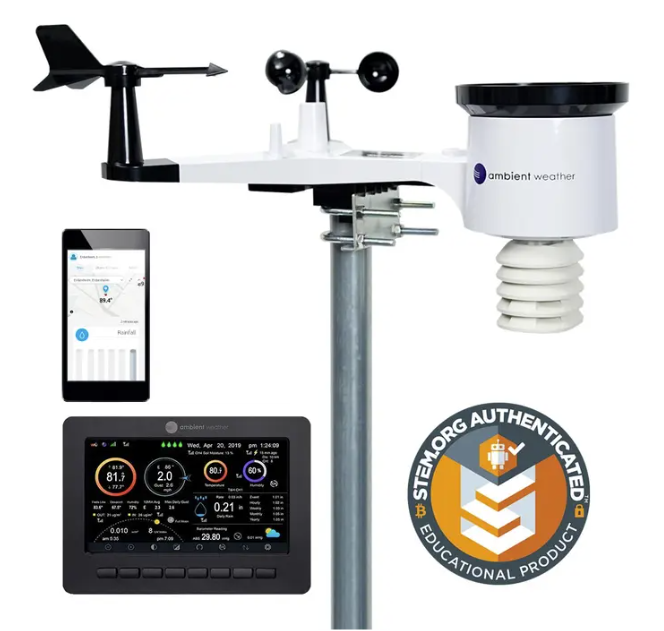
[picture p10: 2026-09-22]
docs/hardware/images/ws-2000.png

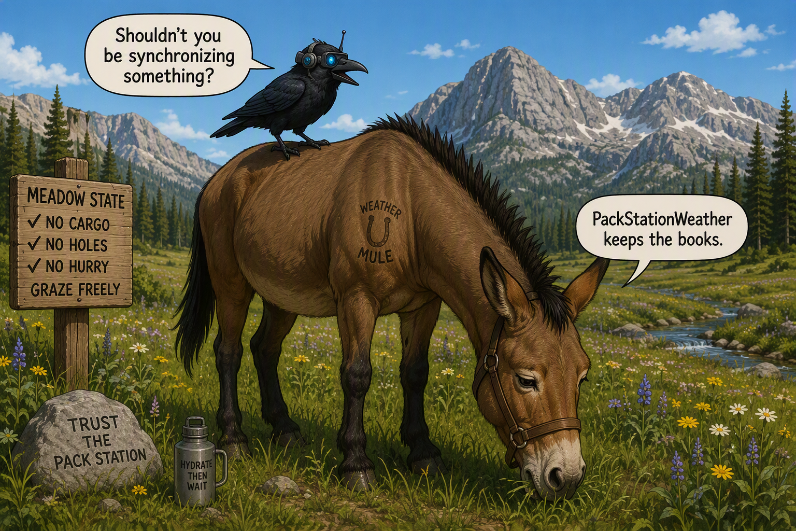
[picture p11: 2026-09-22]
docs/project-story/images/grazing.png

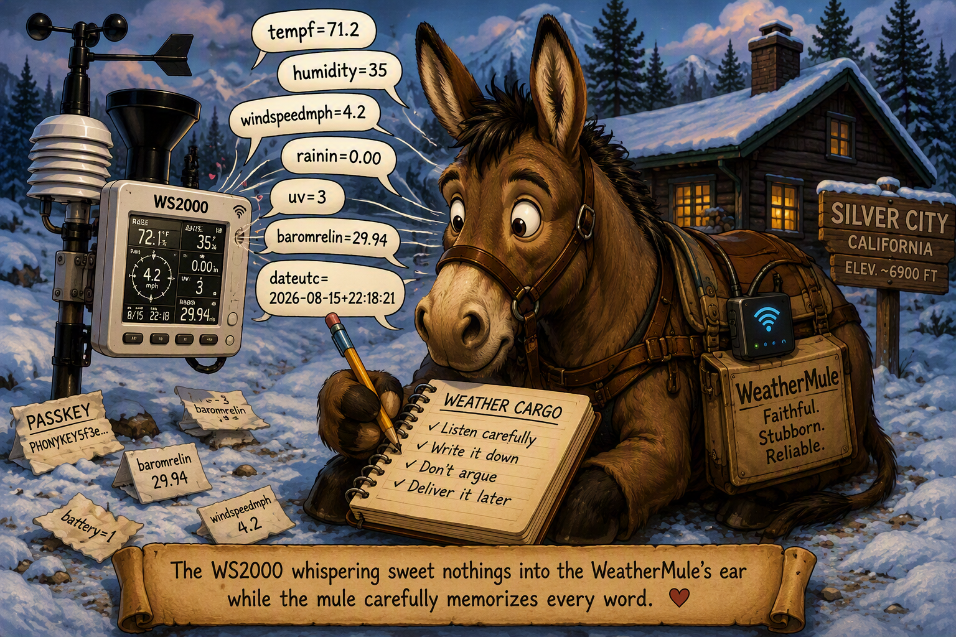
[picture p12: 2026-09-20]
docs/project-story/images/sweet-nothings.png

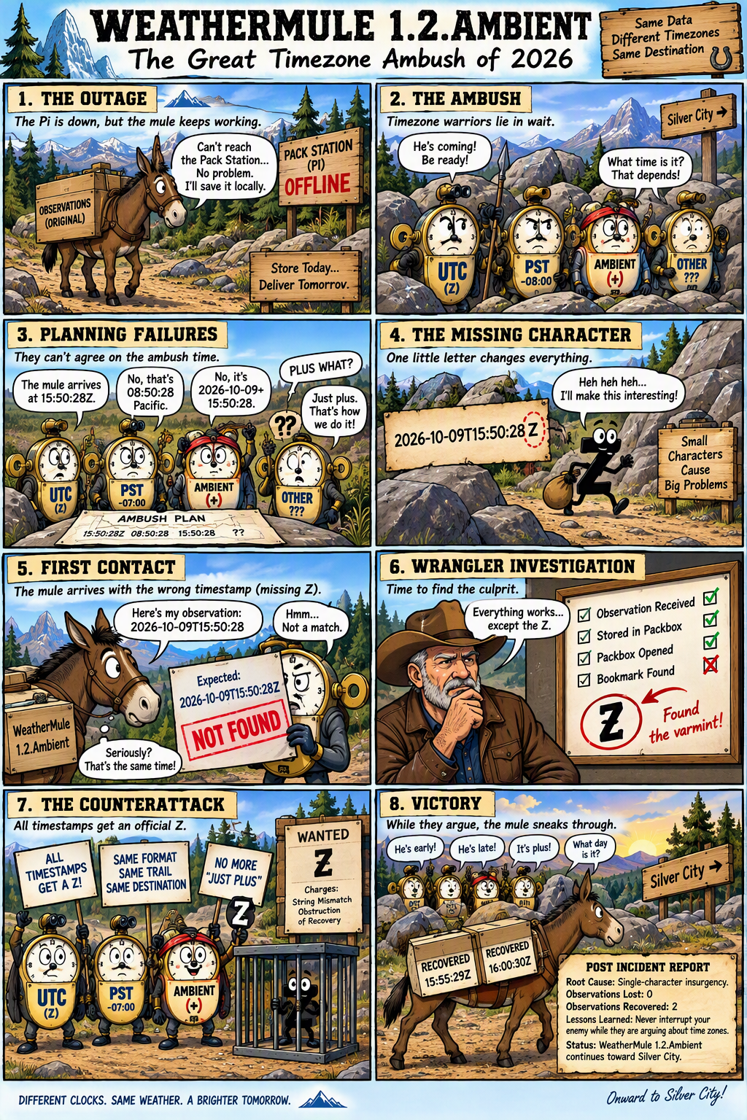
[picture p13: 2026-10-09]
docs/project-story/incidents/images/time-wars.png

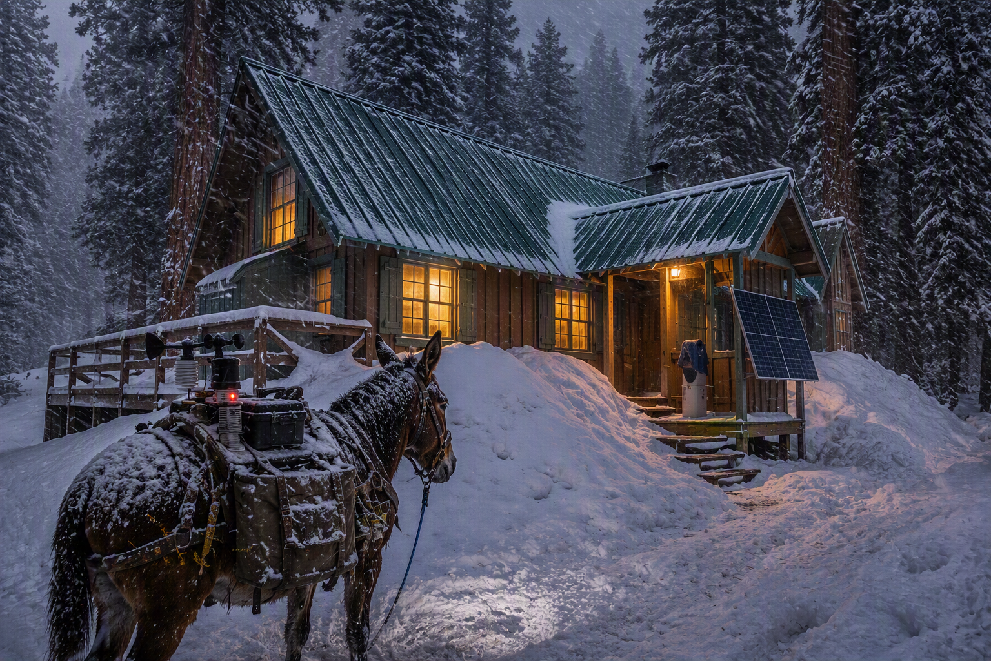
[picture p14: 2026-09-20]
docs/project-story/images/silver-city-cabin.png

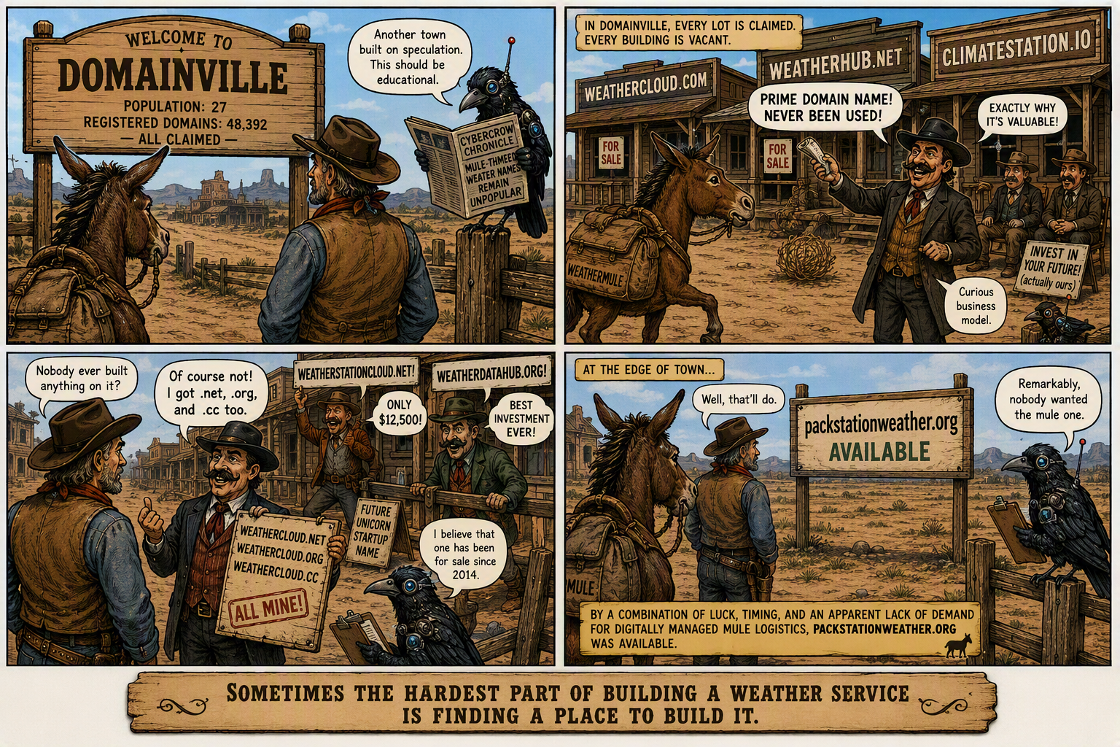
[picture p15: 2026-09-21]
docs/project-story/images/claim-jumpers.png

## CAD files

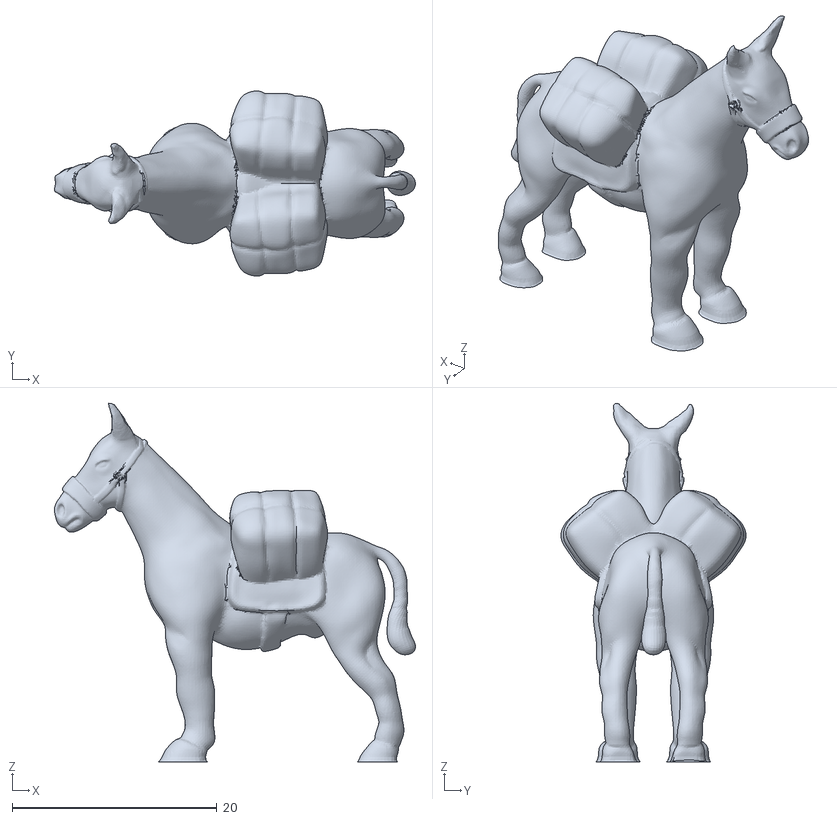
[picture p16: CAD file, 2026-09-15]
docs/hardware/PackMule.stl
35.2 x 18.1 x 35.0

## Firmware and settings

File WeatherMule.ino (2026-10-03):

#include <vector>
#include "weathermule-secrets.h"
#include "WeatherStationRoutines.h"
#include "StorageRoutines.h"
#include "HoleRoutines.h"
#include "Hole.h"
#include <WiFiNINA.h>
#include <WiFiUdp.h>

bool inDesignMode;
int loopCount = 0;

WiFiServer server(80);

bool giveFeedback = false;
bool designModeChanged = false;


void setup() {
  Serial.begin(9600);

  inDesignMode = true;

  LogInformation("Connecting to WiFi...");
  
  while(WiFi.begin(SECRET_SSID, SECRET_PASS) != WL_CONNECTED)
  {
    Serial.print(".");

    delay(1000);
  }

  delay(1000);

  server.begin();

  sdAvailable = InitializeStorage();

  delay(5000);

  LogInformation("SSID: " + String(WiFi.SSID()), true);

  IPAddress ip = WiFi.localIP();
  LogInformation("IP: " + ip.toString(), true);

  byte mac[6];
  WiFi.macAddress(mac);
  LogInformation("Mac: "+ MacToString(mac), true);

  delay(500);

  LogInformation(true);
  LogInformation(true);
}

void loop() {

  WiFiClient incomingWebRequest = server.available();

  if(incomingWebRequest)
  { 
      ProcessWeatherStationRequest(incomingWebRequest);

      delay(500);

      loopCount++;
  }
  else if(holeCount > 0){
    ProcessHoles();
  }

  //delay(500);
}





String MacToString(byte mac[])
{
  String retMac = "";

  for(int i = 0; i < 6; i++)
  {
      if(i > 0)
      {
        retMac += ":";
      }

      retMac += ((mac[i]<16 ? "0" : "") + String(mac[i], HEX));
  }

  return retMac;
}

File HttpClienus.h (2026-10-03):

#pragma once

#include <Arduino.h>
#include <WiFiNINA.h>

//----------------------------------------------
// HTTP response
//----------------------------------------------

class HttpResponsum
{
public:
    String StatusLine;
    int StatusCode;
    String Body;
    bool Succeeded;
    String ErrorMessage;

    HttpResponsum()
        : StatusLine(""),
          StatusCode(0),
          Body(""),
          Succeeded(false),
          ErrorMessage("")
    {
    }
};

//----------------------------------------------
// HTTP methods
//----------------------------------------------

static const String HttpMethods[] =
{
    "GET",
    "POST",
    "PUT",
    "DELETE",
    "PATCH",
    "HEAD",
    "OPTIONS"
};

static const int HttpMethodCount =
    sizeof(HttpMethods) /
    sizeof(HttpMethods[0]);

//----------------------------------------------
// Limits and timeouts
//----------------------------------------------

static const unsigned long HttpResponseTimeoutMs = 10000;
static const unsigned long HttpDataTimeoutMs = 5000;

static const size_t HttpMaxStatusLineLength = 256;
static const size_t HttpMaxHeaderLineLength = 1024;
static const size_t HttpMaxBodyLength = 32768;

//----------------------------------------------
// Prototypes
//----------------------------------------------

inline HttpResponsum HttpRequest(
    const String& host,
    int port,
    const String& method,
    const String& url,
    const String& token,
    const String& userAgent,
    const String& payload);

inline bool IsAllowedHttpMethod(
    const String& method);

inline bool WaitForHttpData(
    WiFiClient& client,
    unsigned long timeoutMs);

inline bool ReadHttpLine(
    WiFiClient& client,
    String& line,
    size_t maximumLength,
    unsigned long timeoutMs);

inline int ParseHttpStatusCode(
    const String& statusLine);

inline bool ReadHttpHeaders(
    WiFiClient& client,
    long& contentLength,
    bool& chunked,
    unsigned long timeoutMs,
    String& errorMessage);

inline bool ReadHttpBody(
    WiFiClient& client,
    String& body,
    long contentLength,
    bool chunked,
    unsigned long timeoutMs,
    String& errorMessage);

inline bool ReadChunkedHttpBody(
    WiFiClient& client,
    String& body,
    unsigned long timeoutMs,
    String& errorMessage);

inline bool ReadExactHttpBytes(
    WiFiClient& client,
    String& destination,
    size_t byteCount,
    unsigned long timeoutMs,
    String& errorMessage);

inline String BuildHeaderAuth(
    const String& token);

inline String BuildUserAgent(
    const String& userAgent);

//----------------------------------------------
// Implementation
//----------------------------------------------

inline HttpResponsum HttpRequest(
    const String& host,
    int port,
    const String& method,
    const String& url,
    const String& token,
    const String& userAgent,
    const String& payload)
{
    HttpResponsum response;
    WiFiClient apiClient;

    String useMethod = method;
    useMethod.trim();
    useMethod.toUpperCase();

    //------------------------------------------
    // Validate request
    //------------------------------------------

    if(host.length() == 0)
    {
        response.ErrorMessage =
            "HTTP host was not provided.";
    }
    else if(port <= 0)
    {
        response.ErrorMessage =
            "HTTP port is invalid.";
    }
    else if(url.length() == 0)
    {
        response.ErrorMessage =
            "HTTP URL was not provided.";
    }
    else if(IsAllowedHttpMethod(useMethod) != true)
    {
        response.ErrorMessage =
            "Unsupported HTTP method: " +
            useMethod;
    }
    else if(apiClient.connect(host.c_str(), port) != true)
    {
        response.ErrorMessage =
            "Unable to connect to " +
            host +
            ":" +
            String(port);
    }
    else
    {
        //--------------------------------------
        // Send request line
        //--------------------------------------

        apiClient.print(useMethod);
        apiClient.print(" ");
        apiClient.print(url);
        apiClient.println(" HTTP/1.1");

        //--------------------------------------
        // Send headers
        //--------------------------------------

        apiClient.print("Host: ");
        apiClient.println(host);

        if(token.length() > 0)
        {
            apiClient.println(
                BuildHeaderAuth(token));
        }

        if(userAgent.length() > 0)
        {
            apiClient.println(
                BuildUserAgent(userAgent));
        }

        apiClient.println("Connection: close");

        //--------------------------------------
        // Send payload headers
        //--------------------------------------

        if(payload.length() > 0)
        {
            apiClient.println(
                "Content-Type: application/json");

            apiClient.print("Content-Length: ");
            apiClient.println(payload.length());
        }

        //--------------------------------------
        // End request headers
        //--------------------------------------

        apiClient.println();

        //--------------------------------------
        // Send payload
        //--------------------------------------

        if(payload.length() > 0)
        {
            apiClient.print(payload);
        }

        //--------------------------------------
        // Wait for response
        //--------------------------------------

        if(WaitForHttpData(apiClient, HttpResponseTimeoutMs) != true)
        {
            response.ErrorMessage =
                "Timed out waiting for HTTP response.";
        }
        else if(ReadHttpLine(apiClient, response.StatusLine, HttpMaxStatusLineLength, HttpDataTimeoutMs) != true)
        {
            response.ErrorMessage =
                "Unable to read HTTP status line.";
        }
        else
        {
            response.StatusCode = ParseHttpStatusCode(response.StatusLine);

            if(response.StatusCode == 0)
            {
                response.ErrorMessage = "Invalid HTTP status line: " + response.StatusLine;
            }
            else
            {
                long contentLength = -1;
                bool chunked = false;

                if(ReadHttpHeaders(apiClient, contentLength, chunked, HttpDataTimeoutMs, response.ErrorMessage) != true)
                {
                    // ErrorMessage set by helper.
                }
                else if(useMethod == "HEAD")
                {
                    response.Succeeded = true;
                }
                else if(ReadHttpBody(apiClient, response.Body, contentLength, chunked, HttpDataTimeoutMs, response.ErrorMessage) != true)
                {
                    // ErrorMessage set by helper.
                }
                else
                {
                    response.Succeeded = true;
                }
            }
        }
    }
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

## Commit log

2026-08-16 Added Arduino Source Code
2026-08-17 cleaned up logging, command switching
2026-09-15 using seek to read packboxes.
    [PackMule.stl]
2026-09-20 documents update
    [PackMule.stl]
2026-09-22 final document push...
    [PackMule.stl]
2026-10-03 The mule gets a new networking brain
    - Added HttpClienus
    - Added HttpResponsum
    - Added timeout protection
    - Added multi-packet response handling
    - Centralized socket management
    - Simplified authentication flow
    - Improved logging and recovery behavior
    Mission: prevent the mule from wandering into the woods and
    forgetting how to talk to the barn.
    [ApiClientRoutines.h, HttpClienus.h, WeatherMule.ino]
2026-11-03 switching to using from and to DateRaw instead of Utc
2026-11-03 using the hole's raw date properties completed.
